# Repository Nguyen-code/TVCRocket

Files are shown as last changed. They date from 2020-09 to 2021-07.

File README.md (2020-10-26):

# About TVCRocket

This project was simultaneously one of the most challenging and most fun projects I've done in a while. I put myself on an extremely strict deadline, only 6 weeks for everything from planning launch sites to putting together 3 rockets (because I wanted to submit some of the work to colleges for applications) and I'm pleased with the progress I was able to make in that time. Going forward, I'm excited to continue development in future versions.

# Design Intent

The overarching goal of this project was to design and develop an active stability system for rockets on the model scale to learn more about robust hardware, software, and mechanical design. Although the first version didn't exactly work perfectly, I learned __SO MUCH__ and am excited to continue on version two, hopefully in the spring of 2021.

# Pictures!

### Zenith Boards (both controller and flight computer)
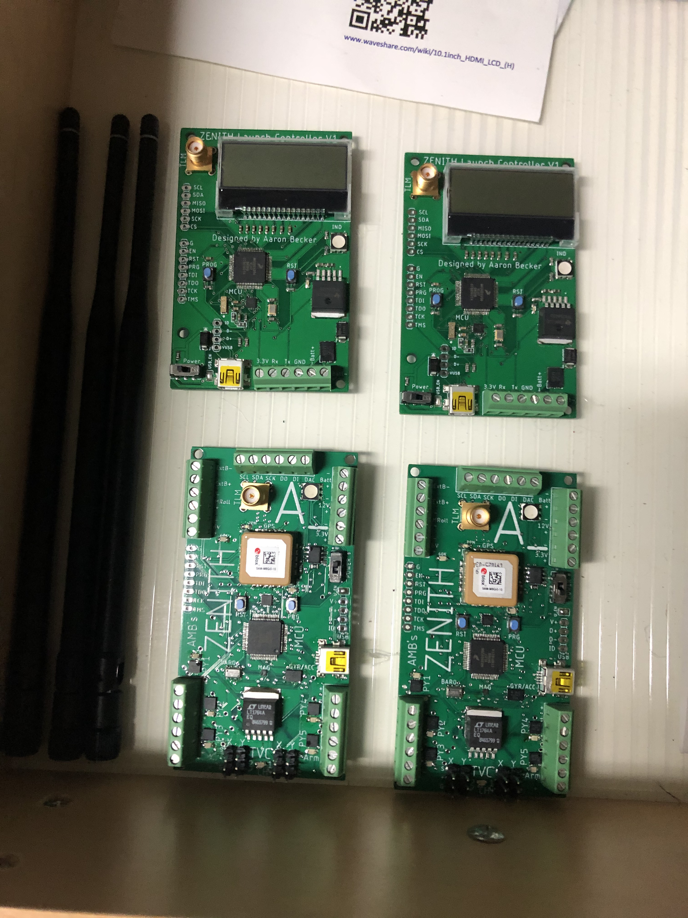
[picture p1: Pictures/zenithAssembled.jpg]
Zenith Boards Finalized


### Rockets before launch
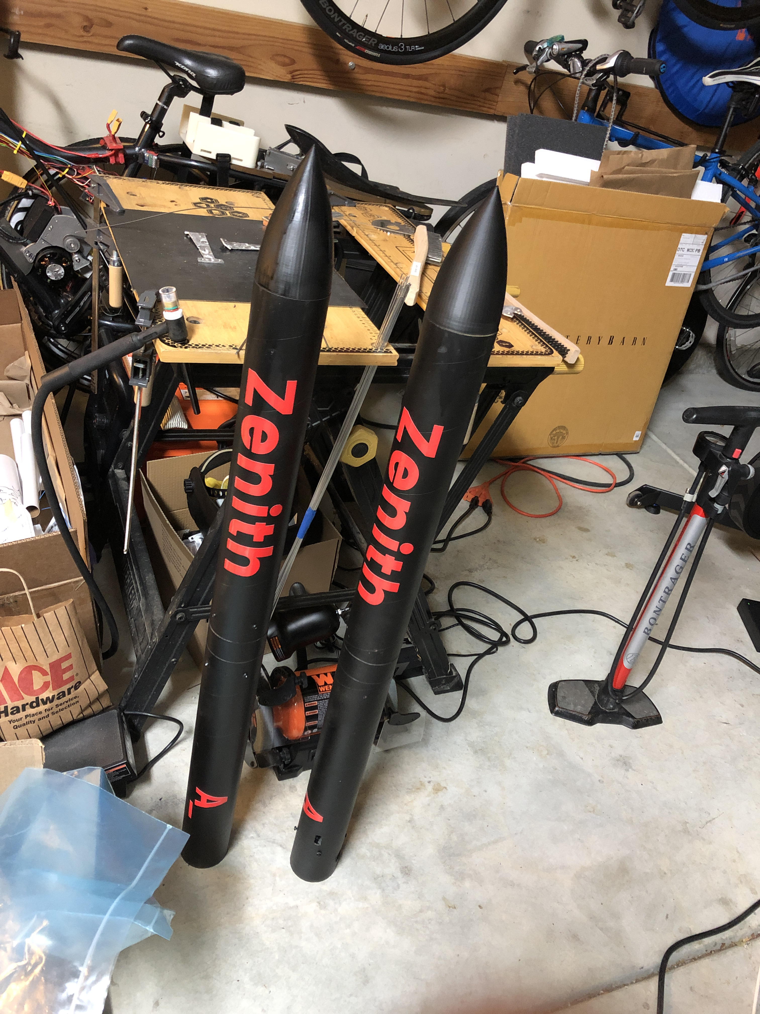
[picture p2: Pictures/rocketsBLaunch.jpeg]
Before Launch


### Rocket at launch site in tuning setup
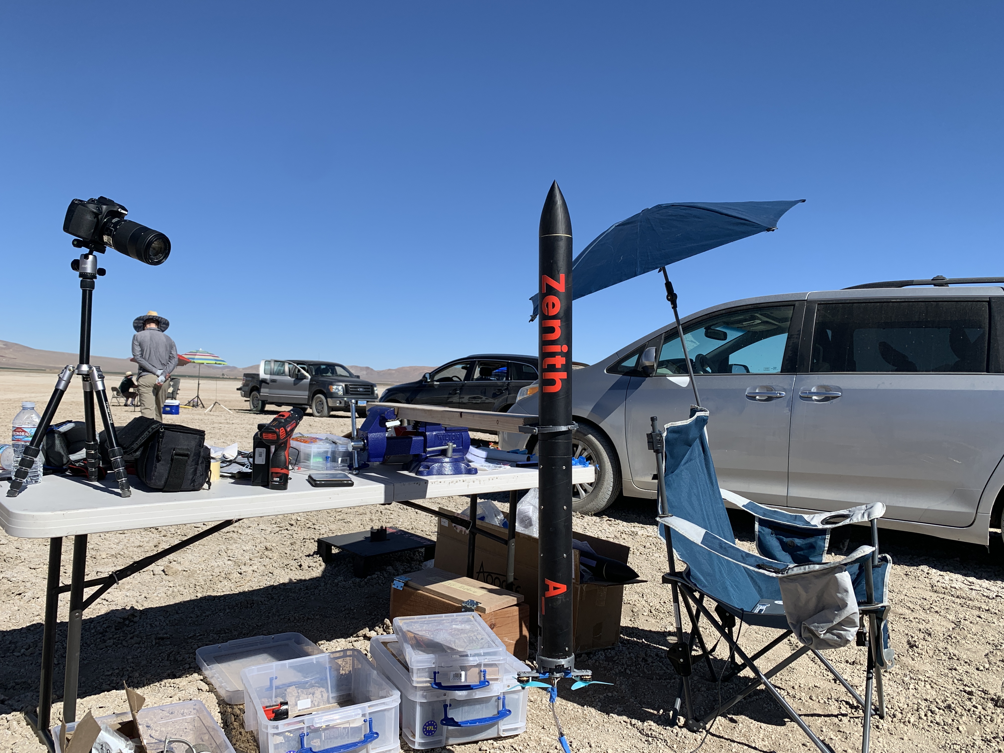
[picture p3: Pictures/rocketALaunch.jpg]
At Launch


# Renderings

## Zenith

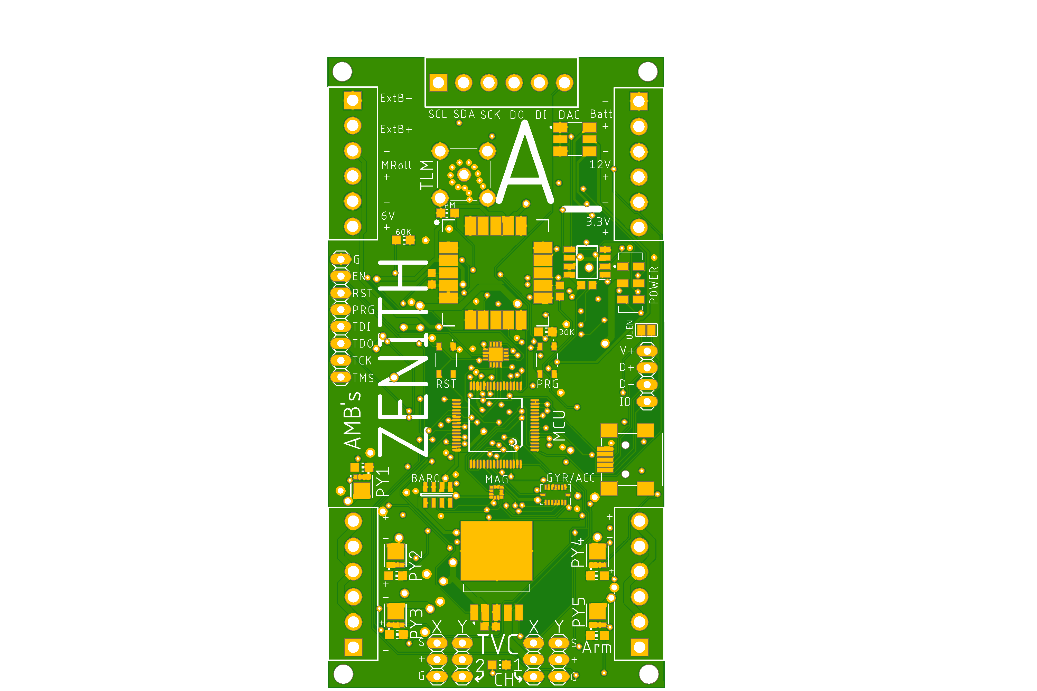
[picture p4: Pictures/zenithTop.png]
Zenith Top

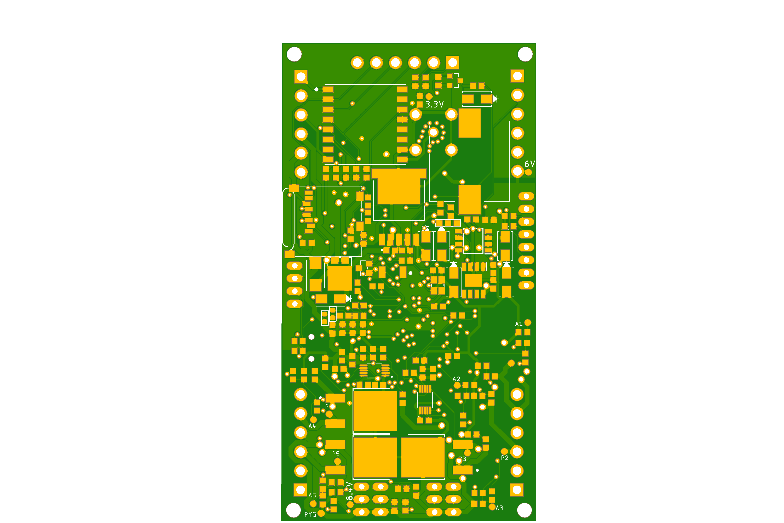
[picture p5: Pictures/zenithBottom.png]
Zenith Bottom


## Controller

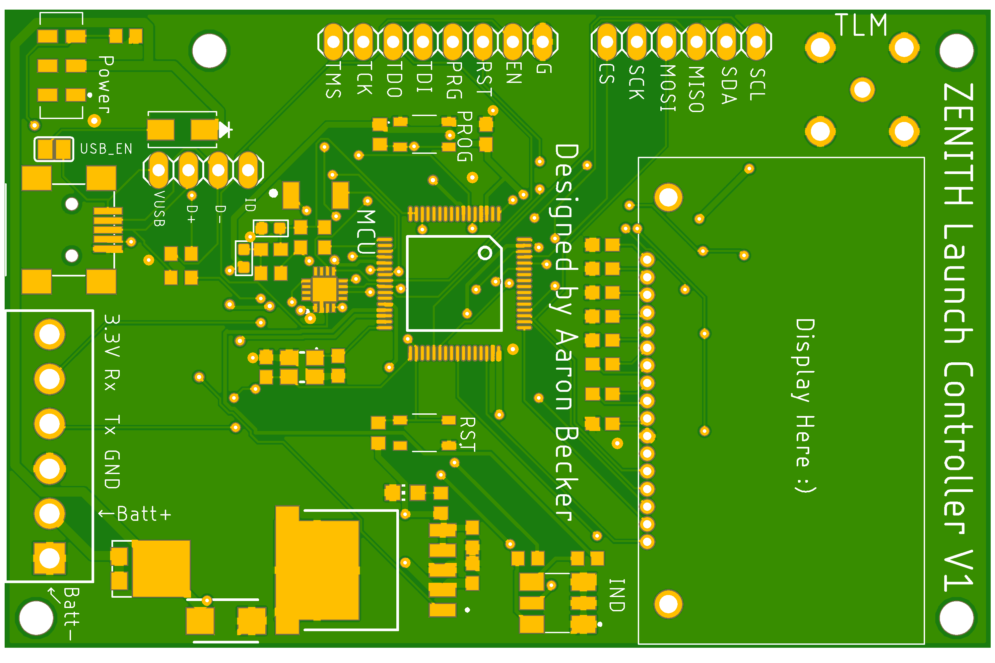
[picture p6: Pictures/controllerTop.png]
Zenith Controller Top

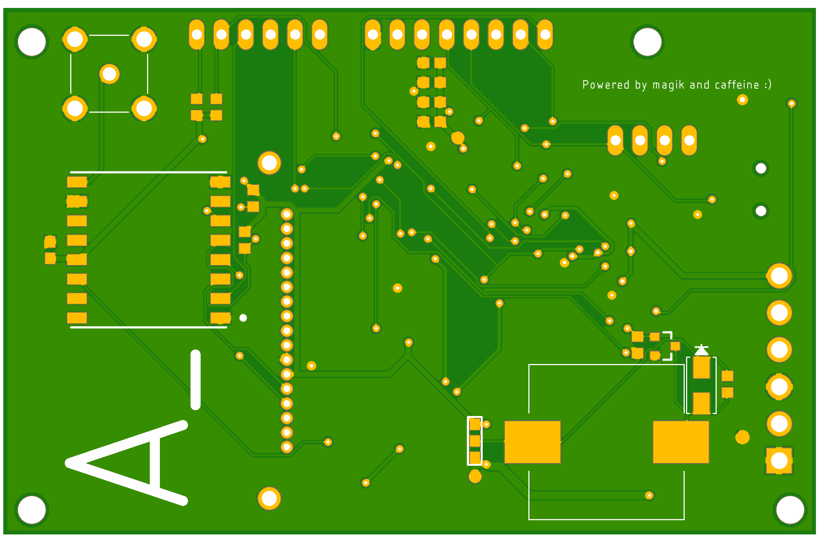
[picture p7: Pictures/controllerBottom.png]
Zenith Conrtoller Bottom


# Disclaimer

This repository contains Technical Data whose export is restricted by the Arms Export Control Act (Title 22, U.S.C., Sec 2751, et seq.). It is for educational purposes only and is not meant to be used in any scenarios which would put individuals in danger. When I launched my rocket, I strictly adhered with NAR/Tripoli safety codes. If you use anything from this repository for any means, you release me (Aaron Becker) from all liability and claims.

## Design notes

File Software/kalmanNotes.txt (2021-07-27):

kalman filter notes:

Reference code:
https://github.com/adafruit/Adafruit_AHRS/blob/master/src/Adafruit_AHRS_NXPFusion.cpp

EKF but python:
https://github.com/diegoavillegasg/IMU-GNSS-Lidar-sensor-fusion-using-Extended-Kalman-Filter-for-State-Estimation/blob/master/es_ekf.py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
https://github.com/diegoavillegasg/IMU-GNSS-Lidar-sensor-fusion-using-Extended-Kalman-Filter-for-State-Estimation/blob/master/es_ekf.py
https://github.com/cyscgzx33/Self_Driving_Car_State_Estimation/blob/master/state_estimate_final_proj/es_ekf.py

Kalman python but sim only:
https://github.com/tottaway/kalman-filters/blob/master/kalman.py

C++ EKF
https://github.com/rsasaki0109/kalman_filter_localization/blob/master/include/kalman_filter_localization/ekf.hpp

EKF but for drones
https://github.com/PX4/ecl

Apparently good theory
https://www.kalmanfilter.net/kalman1d.html

More notes and papers
https://www.researchgate.net/publication/260725857_Vehicle_speed_estimation_using_GPSRISS_Reduced_Inertial_Sensor_System
https://www.bzarg.com/p/how-a-kalman-filter-works-in-pictures/
https://www.mathworks.com/matlabcentral/fileexchange/56652-particle-sigma-point-and-kalman-filters
http://www.anuncommonlab.com/articles/how-kalman-filters-work/

Embedded lib w some great info at the top
https://github.com/pronenewbits/Embedded_EKF_Library/blob/master/ekf_engl/ekf.cpp
https://github.com/pronenewbits/Arduino_AHRS_System/blob/master/ahrs_ekf/ahrs_ekf.ino
https://github.com/pronenewbits/Arduino_AHRS_System/blob/master/ahrs_ekf/ekf.cpp

ACTUAL KALMAN FILTER IMPLEMENTATION FOR ARDUINO (USE THIS)
https://github.com/DanInvents/Flight-Controller
and
https://github.com/TKJElectronics/KalmanFilter/blob/master/examples/MPU6050/MPU6050.ino
https://github.com/FlyTheThings/uNavINS <---- THIS IS PERFECT FOR APPLICATION
https://github.com/ydsf16/imu_gps_localization/blob/master/imu_gps_localizer/src/imu_processor.cpp <---- ALSO THIS
ANOTHER ONE THAT JOE USED https://github.com/simondlevy/TinyEKF

more general sim ref stuff
https://github.com/Zentrik/TVC

BEST RESOURCE
https://github.com/rlabbe/Kalman-and-Bayesian-Filters-in-Python

Notes on Torque based controllers
https://youtu.be/J2ACQsmkPJs?t=411

Quaternion stuff
https://github.com/alexdada555/Rocket-Landing-Control/blob/master/ACS6116%20Assignment%20-%20Rocket%20Landing%20Control%20With%20MPC.pdf

State is represented by a matrix x
Each variable has a mean of mu and a variance of SD^2 - variance=uncertainty

Best estimate is x hat sub k - aka mean of readings
Covariance matrix is P sub k - represents the degree of correlation between the ith and jth state variable

Looking at current state at t=k-1, next state at time K can be mapped by a matrix F sub k, which moves every point to a new estimate

Update covariance matrix by using identity cov(Ax) = AcovAt

U sub k is the control vector - represents what the guidance system is doing to the system
B sub k is the control matrix - represents mapping of the control vector to the system

Add expanded covariance of Q sub k to the covariance matrix

"the new best estimate is a prediction made from previous best estimate, plus a correction for known external influences.

And the new uncertainty is predicted from the old uncertainty, with some additional uncertainty from the environment."

Sensors tell us something indirect about the state - they produce a set of readings
Sensors are modelled by a matrix, H sub k, which is used to map the readings to the state or covariance matrix

Covariance of the sensor uncertainty (i.e. noise) is the matrix R sub k, mean equal to the reading we observed which is a vector, z sub k

If we multiply H sub k and Z sub k, we get the intersection between uncertainty and the sensor reading, which gives us a nice best guess

K is kalman gain matrix that

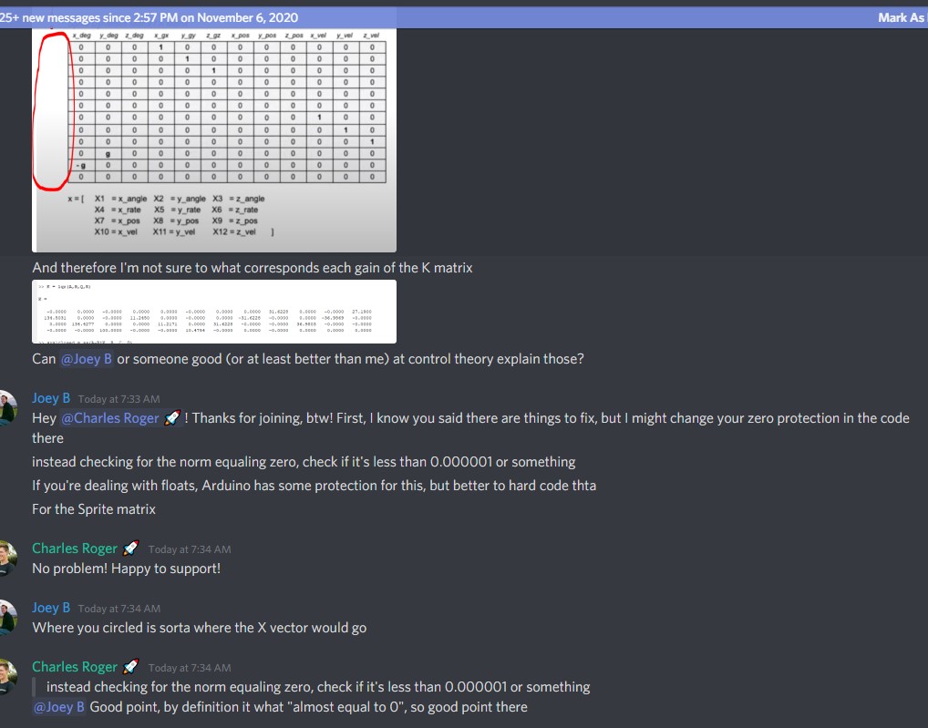
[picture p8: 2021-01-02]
Software/Reference/control theory matrices.jpg

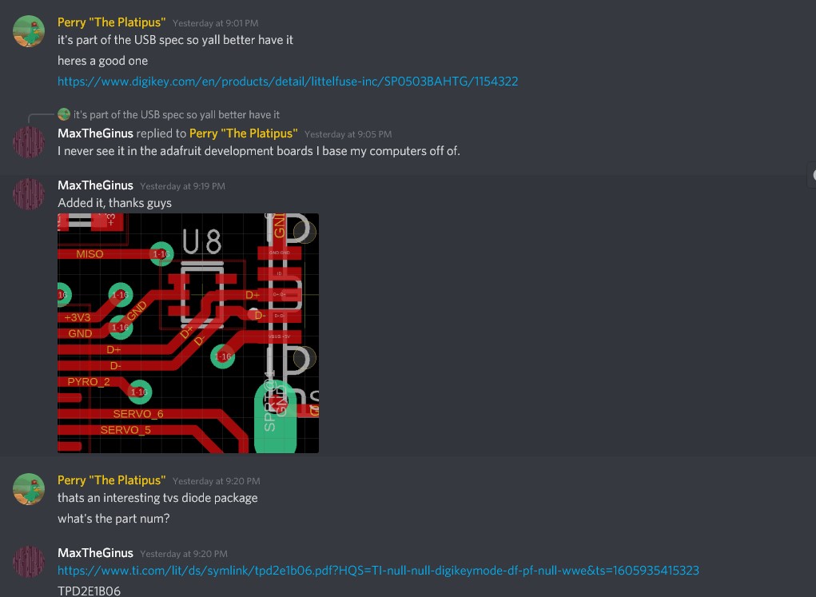
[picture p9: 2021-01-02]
Software/Reference/tvs diode usb spec.jpg

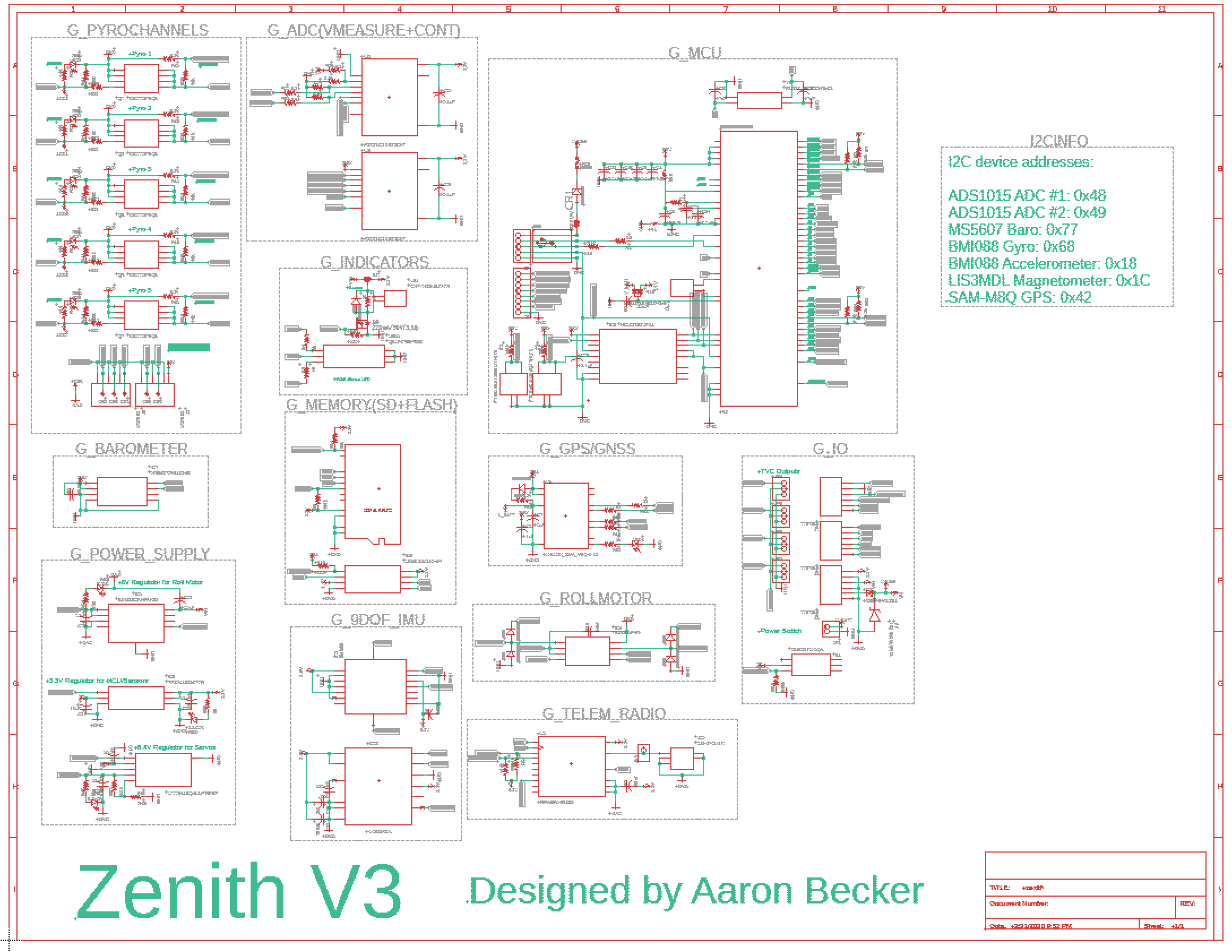
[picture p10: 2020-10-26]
Hardware/Rocket/zenithlowres.png

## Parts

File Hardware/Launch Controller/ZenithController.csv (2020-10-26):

Qty | Value | Device | Package | Parts | Description | ARROW_ELECTRONICS-PURCHASE-URL | ARROW_PART_NUMBER | ARROW_PRICE-STOCK | AVAILABILITY | BUILT_BY | DESC | DESCRIPTION | DIGIKEY-PURCHASE-URL | HEIGHT | MANUFACTURER_NAME | MANUFACTURER_PART_NUMBER | MF | MOUSER-PURCHASE-URL | MOUSER_PART_NUMBER | MOUSER_PRICE-STOCK | MP | MPN | OC_MOUSER | PACKAGE | POPULARITY | PRICE | PROD_ID | SOURCELIBRARY | SPICEPREFIX | TP_SIGNAL_NAME | TYPE | VALUE | VENDOR
2 |  | FERRITE | L0603 | BLM18AG601SN1D, R4 |  |  |  |  |  |  | 600R / 100MHz |  |  |  |  |  | Murata Electronics |  |  |  |  | BLM18AG601SN1D | 81-BLM11A601S | 0603 |  |  |  |  |  |  | Ferrite
1 |  | PINHD-1X4 | 1X04 | JP3 | PIN HEADER |  |  |  |  |  |  |  |  |  |  |  |  |  |  |  |  |  |  |  | 91
1 |  | PINHD-1X6 | 1X06 | JP1 | PIN HEADER |  |  |  |  |  |  |  |  |  |  |  |  |  |  |  |  |  |  |  | 79
1 |  | PINHD-1X8 | 1X08 | JP2 | PIN HEADER |  |  |  |  |  |  |  |  |  |  |  |  |  |  |  |  |  |  |  | 67
1 |  | SJ | SJ | USBPOW | SMD solder JUMPER |  |  |  |  |  |  |  |  |  |  |  |  |  |  |  |  |  |  |  | 33
1 |  | SOLDERJUMPER_2WAY0603 | SOLDERJUMPER_2WAY_OPEN_0603 | SJ1 | 2-Way Solder Jumper
1 |  | USBMINIB | USB-MINIB | CN1 | USB Connectors
6 | 0.1uF | C-USC0603 | C0603 | C3, C5, C18, C20, C23, C24 | CAPACITOR, American symbol |  |  |  |  |  |  |  |  |  |  |  |  |  |  |  |  |  |  |  | 37 |  |  |  | C
6 | 100k | R-US_R0603 | R0603 | R5, R14, R22, R57, R58, R66 | RESISTOR, American symbol |  |  |  |  |  |  |  |  |  |  |  |  |  |  |  |  |  |  |  | 77 |  |  |  | R
3 | 10uF | C-USC0603 | C0603 | C2, C21, C22 | CAPACITOR, American symbol |  |  |  |  |  |  |  |  |  |  |  |  |  |  |  |  |  |  |  | 37 |  |  |  | C
1 | 142-0701-211 | 142-0701-211 | 1420701211 | J10 | Cinch Connectors Straight 50 PCB Mount SMA Connector, jack, Solder Termination |  | 142-0701-211 | https://www.arrow.com/en/products/142-0701-211/cinch-connectivity-solutions |  |  |  | Cinch Connectors Straight 50 PCB Mount SMA Connector, jack, Solder Termination |  | 9.652mm | Cinch Connectivity Solutions | 142-0701-211 |  |  | 530-1420701211 | https://www.mouser.co.uk/ProductDetail/Johnson-Cinch-Connectivity-Solutions/142-0701-211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
1 | 1727052 | 1727052 | SHDR6W105P0X381_1X6_2285X730X8 | J3 | PHOENIX CONTACT - 1727052 - TERMINAL BLOCK, WIRE TO BRD, 6POS, 16AWG |  | 1727052 | https://www.arrow.com/en/products/1727052/phoenix-contact |  |  |  | PHOENIX CONTACT - 1727052 - TERMINAL BLOCK, WIRE TO BRD, 6POS, 16AWG |  | 8.65mm | Phoenix Contact | 1727052 |  |  | 651-1727052 | https://www.mouser.co.uk/ProductDetail/Phoenix-Contact/1727052?qs=WWq3Ki8dym7VpMyTMk0i8A%3D%3D
1 | 1SMB5929BT3G | 1SMB5929BT3G | DIOM5436X247N | Z2 | ON Semiconductor, 15V Zener Diode 5% 550 mW SMT 2-Pin SMB |  | 1SMB5929BT3G | https://www.arrow.com/en/products/1smb5929bt3g/on-semiconductor |  |  |  | ON Semiconductor, 15V Zener Diode 5% 550 mW SMT 2-Pin SMB |  | 2.47mm | ON Semiconductor | 1SMB5929BT3G |  |  | 863-1SMB5929BT3G | https://www.mouser.co.uk/ProductDetail/ON-Semiconductor/1SMB5929BT3G?qs=vLkC5FC1VN%2FFUr7OS2Q1Aw%3D%3D
1 | 1k | R-US_R0603 | R0603 | R7 | RESISTOR, American symbol |  |  |  |  |  |  |  |  |  |  |  |  |  |  |  |  |  |  |  | 77 |  |  |  | R
5 | 1uF | C-USC0603 | C0603 | C1, C7, C8, C9, C10 | CAPACITOR, American symbol |  |  |  |  |  |  |  |  |  |  |  |  |  |  |  |  |  |  |  | 37 |  |  |  | C
2 | 2.2k | R-US_R0603 | R0603 | R1, R2 | RESISTOR, American symbol |  |  |  |  |  |  |  |  |  |  |  |  |  |  |  |  |  |  |  | 77 |  |  |  | R
5 | 2.2uF | C-USC0603 | C0603 | C4, C6, C11, C12, C13 | CAPACITOR, American symbol |  |  |  |  |  |  |  |  |  |  |  |  |  |  |  |  |  |  |  | 37 |  |  |  | C
1 | 220mA/50V/3.5Ω | MOSFET-NCH-BSS138 | SOT23-3 | Q8 | N-channel MOSFETs |  |  |  |  |  |  |  |  |  |  |  |  |  |  |  |  |  |  |  |  |  | TRANS-00830 |  |  |  |  | 220mA/50V/3.5Ω
2 | 33 | R-US_R0603 | R0603 | R8, R16 | RESISTOR, American symbol |  |  |  |  |  |  |  |  |  |  |  |  |  |  |  |  |  |  |  | 77 |  |  |  | R
1 | 470 | R-US_R0603 | R0603 | R21 | RESISTOR, American symbol |  |  |  |  |  |  |  |  |  |  |  |  |  |  |  |  |  |  |  | 77 |  |  |  | R
1 | 5.6 | R-US_R0603 | R0603 | R6 | RESISTOR, American symbol |  |  |  |  |  |  |  |  |  |  |  |  |  |  |  |  |  |  |  | 77 |  |  |  | R
2 | 68 | R-US_R0603 | R0603 | R3, R60 | RESISTOR, American symbol |  |  |  |  |  |  |  |  |  |  |  |  |  |  |  |  |  |  |  | 77 |  |  |  | R
2 | 7pF | C-USC0603 | C0603 | C30, C31 | CAPACITOR, American symbol |  |  |  |  |  |  |  |  |  |  |  |  |  |  |  |  |  |  |  | 37 |  |  |  | C
1 | ABS10-32.768KHZ-9-T | ABS10-32.768KHZ-9-T | ABS-10 | Y2 | ABRACON - ABS10-32.768KHZ-9-T - Crystal, 32.768 kHz, SMD, 4.9mm x 1.8mm, 9 pF, 20 ppm, ABS10 Series |  | ABS10-32.768KHZ-9-T | https://www.arrow.com/en/products/abs10-32.768khz-9-t/abracon |  |  |  | ABRACON - ABS10-32.768KHZ-9-T - Crystal, 32.768 kHz, SMD, 4.9mm x 1.8mm, 9 pF, 20 ppm, ABS10 Series |  | mm | ABRACON | ABS10-32.768KHZ-9-T |  |  | 815-ABS10-32.768K9T | https://www.mouser.co.uk/ProductDetail/ABRACON/ABS10-32768KHZ-9-T?qs=76dmnhCH%2FMO8FcjiLkcQ2w%3D%3D
2 | B120-13-F | B120-13-F | SMA_DIO | CR1, CR2 |  |  |  |  |  | EMA_UL_Team |  |  |  |  |  | B120-13-F |  |  |  |  |  |  |  |  |  |  |  | DiodesInc_2015-05-08 |  |  |  |  | Diodes Inc
1 | CMT-1603-SMT-TR | CMT-1603-SMT-TR | CMT1603SMTTR | LS1 | AUDIO PIEZO TRANSDUCER 25V SMD |  | CMT-1603-SMT-TR | https://www.arrow.com/en/products/cmt-1603-smt-tr/cui-devices |  |  |  | AUDIO PIEZO TRANSDUCER 25V SMD |  | 2.8mm | CUI Devices | CMT-1603-SMT-TR |  |  | 490-CMT-1603-SMT-TR | https://www.mouser.co.uk/ProductDetail/CUI-Devices/CMT-1603-SMT-TR?qs=WyjlAZoYn50AZ4xT4ox6zw%3D%3D
1 | FA-238_16.0000MB-K3 | FA-238_16.0000MB-K3 | EPSON-FA-238 | FA-23816.0000MA30X-AG0 | Crystal 16MHz |  | FA-238 16.0000MB-K3 | https://www.arrow.com/en/products/fa-23816.0000mb-k3/epson-electronics-america |  |  |  | Crystal 16MHz |  | mm | Epson Timing | FA-238 16.0000MB-K3 |  |  | 732-FA238-16B-K3 | https://www.mouser.co.uk/ProductDetail/Epson-Timing/FA-238-160000MB-K3?qs=CANAagUtPAoF3w0fRAI0xg%3D%3D
1 | JS202011JCQN | JS202011JCQN | JS202011JCQN | S4 | Slide Switch DPDT Surface Mount |  | JS202011JCQN | https://www.arrow.com/en/products/js202011jcqn/ck |  |  |  | Slide Switch DPDT Surface Mount |  | 5mm | C & K COMPONENTS | JS202011JCQN |  |  | 611-JS202011JCQN | https://www.mouser.co.uk/ProductDetail/CK/JS202011JCQN?qs=74EMXstkWMXJzVJFnXPbEg%3D%3D
1 | MK20DX256VLH7 | MK20DX256VLH7 | LQFP64-05 | K3 |  |  |  |  |  |  | MK20DX256VLH7 |  |  |  |  |  | NXP |  |  |  |  | MK20DX256VLH7 | 841-MK20DX256VLH7 | LQFP-64 |  |  |  |  |  |  | Microcontroller
1 | MKL02Z32VFG4 | MKL02Z32VFG4 | QFN50P300X300X65-17N | IC5 | NXP MKL02Z32VFG4, 32bit ARM Cortex M0 Microcontroller, 48MHz, 32 kB Flash, 16-Pin QFN |  | MKL02Z32VFG4 | https://www.arrow.com/en/products/mkl02z32vfg4/nxp-semiconductors |  |  |  | NXP MKL02Z32VFG4, 32bit ARM Cortex M0 Microcontroller, 48MHz, 32 kB Flash, 16-Pin QFN |  | 0.65mm | NXP | MKL02Z32VFG4 |  |  | 841-MKL02Z32VFG4 | https://www.mouser.co.uk/ProductDetail/NXP-Semiconductors/MKL02Z32VFG4?qs=RECgZY%252BK1xLpPFD7GzHxWg%3D%3D
1 | NHD-C12832A1Z-FSW-FBW-3V3 | NHD-C12832A1Z-FSW-FBW-3V3 | NHDC12832A1ZFSWFBW3V3 | DS1 | LCD Graphic Display Modules & Accessories FSTN (+) 41.4 x 24.3 x 4.0 |  | NHD-C12832A1Z-FSW-FBW-3V3 |  |  |  |  | LCD Graphic Display Modules & Accessories FSTN (+) 41.4 x 24.3 x 4.0 |  | 4.3mm | Newhaven Display | NHD-C12832A1Z-FSW-FBW-3V3 |  |  | 763-C12832A1ZFSWFBW3 | https://www.mouser.co.uk/ProductDetail/Newhaven-Display/NHD-C12832A1Z-FSW-FBW-3V3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
2 | PTS810SJG250SMTRLFS | PTS810SJG250SMTRLFS | PTS810SJG250SMTRLFS | S2, S3 | PTS810SJG250SMTRLFS (Tactile Switches) Switch Tactile N.O. SPST Button J-Bend 0.05A 16VDC 100000Cycles 3.92N SMD T/R |  | PTS810SJG250SMTRLFS |  |  |  |  | PTS810SJG250SMTRLFS (Tactile Switches) Switch Tactile N.O. SPST Button J-Bend 0.05A 16VDC 100000Cycles 3.92N SMD T/R |  | 2.7mm | C & K COMPONENTS | PTS810SJG250SMTRLFS |  |  | 611-PTS810SJG250SMTR | https://www.mouser.co.uk/ProductDetail/CK/PTS810SJG250SMTRLFS?qs=UxeAxwACbqndUPIQjZosiw%3D%3D
1 | QBLP679E-RGB | QBLP679E-RGB | QBLP679ERGB | LED1 | LED RGB DIFFUSED 6PLCC SMD |  | QBLP679E-RGB |  |  |  |  | LED RGB DIFFUSED 6PLCC SMD |  | 1.8mm | QT Brightek (QTB) | QBLP679E-RGB
1 | RED | LEDCHIP-LED0805 | CHIP-LED0805 | 3.3VOK | LED |  |  |  |  |  |  |  |  |  |  |  |  |  |  |  |  |  |  |  | 68
1 | RFM95W-868S2 | RFM95W-868S2 | XCVR_RFM95W-868S2 | U1 | Mod Txrx Lora +20dbm 868mhz Smd |  |  |  | Unavailable |  |  | General ISM < 1GHz LoRa™ Transceiver Module 868MHz Antenna Not Included Surface Mount |  |  |  |  | RF |  |  |  | RFM95W-868S2 |  |  | SMD-16 Hope Microelectronics |  | None
1 | SS5P6-M3/86A | SS5P6-M3/86A | TO-277A(SMPC) | D2 | Vishay | https://snapeda.com/shop?store=Arrow+Electronics&id=580592 |  |  | Unavailable |  |  | Diode Schottky 60V 5A Surface Mount TO-277A (SMPC) | https://snapeda.com/shop?store=DigiKey&id=580592 |  |  |  | Vishay Semiconductor | https://snapeda.com/shop?store=Mouser&id=580592 |  |  | SS5P6-M3/86A |  |  | TO-277 Vishay Semiconductor |  | None
3 | TPB1,27 | TPB1,27 | B1,27 | 3.3V, GND, VIN | Test pad |  |  |  |  |  |  |  |  |  |  |  |  |  |  |  |  |  |  |  | 19
1 | TPS7A4533KTTR | TPS7A4533KTTR | KTT0005B | IC6 | Low-Noise Fast-Transient-Response 1.5-A Low-Dropout Voltage Regulators |  | TPS7A4533KTTR | https://www.arrow.com/en/products/tps7a4533kttr/texas-instruments |  |  |  | Low-Noise Fast-Transient-Response 1.5-A Low-Dropout Voltage Regulators |  | mm | Texas Instruments | TPS7A4533KTTR |  |  | 595-TPS7A4533KTTR | https://www.mouser.co.uk/ProductDetail/Texas-Instruments/TPS7A4533KTTR?qs=VdEABdpqjWy1AK9ieQmsYg%3D%3D

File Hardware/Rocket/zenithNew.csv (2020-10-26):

Qty | Value | Device | Package | Parts | Description | ARROW_ELECTRONICS-PURCHASE-URL | ARROW_PART_NUMBER | ARROW_PRICE-STOCK | AVAILABILITY | BUILT_BY | DESC | DESCRIPTION | DIGI-KEY_PART_NUMBER | DIGIKEY-PURCHASE-URL | HEIGHT | MANUFACTURER_NAME | MANUFACTURER_PART_NUMBER | MF | MOUSER-PURCHASE-URL | MOUSER_PART_NUMBER | MOUSER_PRICE-STOCK | MP | MPN | OC_MOUSER | PACKAGE | POPULARITY | PRICE | PROD_ID | SOURCELIBRARY | SPICEPREFIX | TEXAS_INSTRUMENTS-PURCHASE-URL | TP_SIGNAL_NAME | TYPE | VALUE | VENDOR
1 |  | DIODE_DUAL | SOT-23 | BAT54C,215 |  |  |  |  |  |  | Dual Schottky, common cat |  |  |  |  |  |  | NXP Semiconductors |  |  |  |  | BAT54C,215 | 771-BAT54C-T/R | SOT-23 |  |  |  |  |  |  |  | Diode
2 |  | FERRITE | L0603 | BLM18AG601SN1D, R4 |  |  |  |  |  |  | 600R / 100MHz |  |  |  |  |  |  | Murata Electronics |  |  |  |  | BLM18AG601SN1D | 81-BLM11A601S | 0603 |  |  |  |  |  |  |  | Ferrite
1 |  | LEDCHIP-LED0805 | CHIP-LED0805 | LED6 | LED |  |  |  |  |  |  |  |  |  |  |  |  |  |  |  |  |  |  |  |  | 68
4 |  | PINHD-1X3 | 1X03 | JP4, JP5, JP6, JP7 | PIN HEADER |  |  |  |  |  |  |  |  |  |  |  |  |  |  |  |  |  |  |  |  | 92
1 |  | PINHD-1X4 | 1X04 | JP3 | PIN HEADER |  |  |  |  |  |  |  |  |  |  |  |  |  |  |  |  |  |  |  |  | 91
1 |  | PINHD-1X8 | 1X08 | JP2 | PIN HEADER |  |  |  |  |  |  |  |  |  |  |  |  |  |  |  |  |  |  |  |  | 67
1 |  | SJ | SJ | USBPOW | SMD solder JUMPER |  |  |  |  |  |  |  |  |  |  |  |  |  |  |  |  |  |  |  |  | 33
1 |  | SOLDERJUMPER_2WAY0603 | SOLDERJUMPER_2WAY_OPEN_0603 | SJ1 | 2-Way Solder Jumper
1 |  | USBMINIB | USB-MINIB | CN1 | USB Connectors
8 | 0.1uF | C-USC0603 | C0603 | C3, C5, C10, C18, C19, C20, C23, C24 | CAPACITOR, American symbol |  |  |  |  |  |  |  |  |  |  |  |  |  |  |  |  |  |  |  |  | 37 |  |  |  | C
5 | 100 | R-US_R0603 | R0603 | R29, R33, R38, R43, R48 | RESISTOR, American symbol |  |  |  |  |  |  |  |  |  |  |  |  |  |  |  |  |  |  |  |  | 77 |  |  |  | R
1 | 1000 | R-US_R0603 | R0603 | R11 | RESISTOR, American symbol |  |  |  |  |  |  |  |  |  |  |  |  |  |  |  |  |  |  |  |  | 77 |  |  |  | R
13 | 100k | R-US_R0603 | R0603 | R5, R9, R12, R14, R22, R27, R34, R39, R44, R49, R57, R58, R66 | RESISTOR, American symbol |  |  |  |  |  |  |  |  |  |  |  |  |  |  |  |  |  |  |  |  | 77 |  |  |  | R
3 | 100nF | C-USC0603 | C0603 | C1, C9, C11 | CAPACITOR, American symbol |  |  |  |  |  |  |  |  |  |  |  |  |  |  |  |  |  |  |  |  | 37 |  |  |  | C
1 | 10k | R-US_R0603 | R0603 | R24 | RESISTOR, American symbol |  |  |  |  |  |  |  |  |  |  |  |  |  |  |  |  |  |  |  |  | 77 |  |  |  | R
8 | 10uF | C-USC0603 | C0603 | C2, C12, C15, C21, C22, C25, C26, C29 | CAPACITOR, American symbol |  |  |  |  |  |  |  |  |  |  |  |  |  |  |  |  |  |  |  |  | 37 |  |  |  | C
1 | 142-0701-211 | 142-0701-211 | 1420701211 | J10 | Cinch Connectors Straight 50 PCB Mount SMA Connector, jack, Solder Termination |  | 142-0701-211 | https://www.arrow.com/en/products/142-0701-211/cinch-connectivity-solutions |  |  |  | Cinch Connectors Straight 50 PCB Mount SMA Connector, jack, Solder Termination |  |  | 9.652mm | Cinch Connectivity Solutions | 142-0701-211 |  |  | 530-1420701211 | https://www.mouser.co.uk/ProductDetail/Johnson-Cinch-Connectivity-Solutions/142-0701-211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
5 | 1727052 | 1727052 | SHDR6W105P0X381_1X6_2285X730X8 | J1, J2, J3, J4, J9 | PHOENIX CONTACT - 1727052 - TERMINAL BLOCK, WIRE TO BRD, 6POS, 16AWG |  | 1727052 | https://www.arrow.com/en/products/1727052/phoenix-contact |  |  |  | PHOENIX CONTACT - 1727052 - TERMINAL BLOCK, WIRE TO BRD, 6POS, 16AWG |  |  | 8.65mm | Phoenix Contact | 1727052 |  |  | 651-1727052 | https://www.mouser.co.uk/ProductDetail/Phoenix-Contact/1727052?qs=WWq3Ki8dym7VpMyTMk0i8A%3D%3D
1 | 1SMB5929BT3G | 1SMB5929BT3G | DIOM5436X247N | Z2 | ON Semiconductor, 15V Zener Diode 5% 550 mW SMT 2-Pin SMB |  | 1SMB5929BT3G | https://www.arrow.com/en/products/1smb5929bt3g/on-semiconductor |  |  |  | ON Semiconductor, 15V Zener Diode 5% 550 mW SMT 2-Pin SMB |  |  | 2.47mm | ON Semiconductor | 1SMB5929BT3G |  |  | 863-1SMB5929BT3G | https://www.mouser.co.uk/ProductDetail/ON-Semiconductor/1SMB5929BT3G?qs=vLkC5FC1VN%2FFUr7OS2Q1Aw%3D%3D
8 | 1k | R-US_R0603 | R0603 | R7, R25, R30, R35, R40, R45, R50, R52 | RESISTOR, American symbol |  |  |  |  |  |  |  |  |  |  |  |  |  |  |  |  |  |  |  |  | 77 |  |  |  | R
2 | 1uF | C-USC0603 | C0603 | C7, C8 | CAPACITOR, American symbol |  |  |  |  |  |  |  |  |  |  |  |  |  |  |  |  |  |  |  |  | 37 |  |  |  | C
4 | 2.2k | R-US_R0603 | R0603 | R1, R2, R63, R64 | RESISTOR, American symbol |  |  |  |  |  |  |  |  |  |  |  |  |  |  |  |  |  |  |  |  | 77 |  |  |  | R
2 | 2.2uF | C-USC0603 | C0603 | C4, C6 | CAPACITOR, American symbol |  |  |  |  |  |  |  |  |  |  |  |  |  |  |  |  |  |  |  |  | 37 |  |  |  | C
2 | 22 | R-US_R0603 | R0603 | R53, R54 | RESISTOR, American symbol |  |  |  |  |  |  |  |  |  |  |  |  |  |  |  |  |  |  |  |  | 77 |  |  |  | R
6 | 220 | R-US_R0603 | R0603 | R23, R32, R37, R42, R47, R59 | RESISTOR, American symbol |  |  |  |  |  |  |  |  |  |  |  |  |  |  |  |  |  |  |  |  | 77 |  |  |  | R
1 | 220mA/50V/3.5Ω | MOSFET-NCH-BSS138 | SOT23-3 | Q8 | N-channel MOSFETs |  |  |  |  |  |  |  |  |  |  |  |  |  |  |  |  |  |  |  |  |  |  | TRANS-00830 |  |  |  |  |  | 220mA/50V/3.5Ω
2 | 3.3k | R-US_R0603 | R0603 | R15, R61 | RESISTOR, American symbol |  |  |  |  |  |  |  |  |  |  |  |  |  |  |  |  |  |  |  |  | 77 |  |  |  | R
2 | 33 | R-US_R0603 | R0603 | R8, R16 | RESISTOR, American symbol |  |  |  |  |  |  |  |  |  |  |  |  |  |  |  |  |  |  |  |  | 77 |  |  |  | R
7 | 330 | R-US_R0603 | R0603 | R26, R31, R36, R41, R46, R51, R65 | RESISTOR, American symbol |  |  |  |  |  |  |  |  |  |  |  |  |  |  |  |  |  |  |  |  | 77 |  |  |  | R
3 | 470 | R-US_R0603 | R0603 | R17, R18, R21 | RESISTOR, American symbol |  |  |  |  |  |  |  |  |  |  |  |  |  |  |  |  |  |  |  |  | 77 |  |  |  | R
1 | 5.6 | R-US_R0603 | R0603 | R6 | RESISTOR, American symbol |  |  |  |  |  |  |  |  |  |  |  |  |  |  |  |  |  |  |  |  | 77 |  |  |  | R
2 | 560 | R-US_R0603 | R0603 | R62, R68 | RESISTOR, American symbol |  |  |  |  |  |  |  |  |  |  |  |  |  |  |  |  |  |  |  |  | 77 |  |  |  | R
1 | 620 | R-US_R0603 | R0603 | R10 | RESISTOR, American symbol |  |  |  |  |  |  |  |  |  |  |  |  |  |  |  |  |  |  |  |  | 77 |  |  |  | R
2 | 68 | R-US_R0603 | R0603 | R3, R60 | RESISTOR, American symbol |  |  |  |  |  |  |  |  |  |  |  |  |  |  |  |  |  |  |  |  | 77 |  |  |  | R
1 | 680 | R-US_R0603 | R0603 | R67 | RESISTOR, American symbol |  |  |  |  |  |  |  |  |  |  |  |  |  |  |  |  |  |  |  |  | 77 |  |  |  | R
2 | 7pF | C-USC0603 | C0603 | C30, C31 | CAPACITOR, American symbol |  |  |  |  |  |  |  |  |  |  |  |  |  |  |  |  |  |  |  |  | 37 |  |  |  | C
1 | ABS10-32.768KHZ-9-T | ABS10-32.768KHZ-9-T | ABS-10 | Y2 | ABRACON - ABS10-32.768KHZ-9-T - Crystal, 32.768 kHz, SMD, 4.9mm x 1.8mm, 9 pF, 20 ppm, ABS10 Series |  | ABS10-32.768KHZ-9-T | https://www.arrow.com/en/products/abs10-32.768khz-9-t/abracon |  |  |  | ABRACON - ABS10-32.768KHZ-9-T - Crystal, 32.768 kHz, SMD, 4.9mm x 1.8mm, 9 pF, 20 ppm, ABS10 Series |  |  | mm | ABRACON | ABS10-32.768KHZ-9-T |  |  | 815-ABS10-32.768K9T | https://www.mouser.co.uk/ProductDetail/ABRACON/ABS10-32768KHZ-9-T?qs=76dmnhCH%2FMO8FcjiLkcQ2w%3D%3D
2 | ADS1015IDGST | ADS1015IDGST | SOP50P490X110-10N | U2, U6 |  |  |  |  |  |  |  | 12-Bit, 3.3kSPS, 4-Ch Delta-Sigma ADC With PGA, Oscillator, VREF, Comparator and I2C Interface 10-VSSOP -40 to 125 | 296-25227-1-ND |  |  |  |  | Texas Instruments |  |  |  | ADS1015IDGST |  |  | VSSOP-10 Texas Instruments |  |  |  |  |  | https://snapeda.com/shop?store=Texas+Instruments&id=425936
4 | B120-13-F | B120-13-F | SMA_DIO | CR1, CR2, CR5, CR6 |  |  |  |  |  | EMA_UL_Team |  |  |  |  |  |  | B120-13-F |  |  |  |  |  |  |  |  |  |  |  | DiodesInc_2015-05-08 |  |  |  |  |  | Diodes Inc
3 | B120-13-FNO_LABELS | B120-13-FNO_LABELS | SMA_NO_LABELS | CR3, CR4, CR7
1 | BD60GC0WEFJ-E2 | BD60GC0WEFJ-E2 | SOIC127P600X100-9N | IC1 | LDO Regulator 6V 1% 1A 4.5-14V HTSOP8 |  | BD60GC0WEFJ-E2 |  |  |  |  | LDO Regulator 6V 1% 1A 4.5-14V HTSOP8 |  |  | 1mm | ROHM Semiconductor | BD60GC0WEFJ-E2 |  |  | 755-BD60GC0WEFJ-E2 | https://www.mouser.co.uk/ProductDetail/ROHM-Semiconductor/BD60GC0WEFJ-E2?qs=QbAZ1slfEbRabsfnpcxbEg%3D%3D
1 | BD6211F-E2 | BD6211F-E2 | SOIC127P620X171-8N | IC4 | ROHM BD6211F-E2, Full Bridge Motor Driver Half-Bridge,, 8-Pin SOP |  | BD6211F-E2 | https://www.arrow.com/en/products/bd6211f-e2/rohm-semiconductor |  |  |  | ROHM BD6211F-E2, Full Bridge Motor Driver Half-Bridge,, 8-Pin SOP |  |  | 1.71mm | ROHM Semiconductor | BD6211F-E2 |  |  | 755-BD6211F-E2 | https://www.mouser.co.uk/ProductDetail/ROHM-Semiconductor/BD6211F-E2?qs=WqWCsLCZBkoJxAu8uKdYEg%3D%3D
1 | BMI088 | BMI088 | BMI088 | IC2 | Inertial Measurement Unit Digital Output 2.5V/3.3V Automotive |  | BMI088 | https://www.arrow.com/en/products/bmi088/bosch |  |  |  | Inertial Measurement Unit Digital Output 2.5V/3.3V Automotive |  |  | 1.45mm | Bosch Sensortec | BMI088 |  |  | 262-BMI088 | https://www.mouser.co.uk/ProductDetail/Bosch-Sensortec/BMI088?qs=f9yNj16SXrIMFspTV6RB6Q%3D%3D
1 | BMM150 | BMM150 | BMM150 | IC3 | Board Mount Hall Effect / Magnetic Sensors 3-Axis 1.56x1.56mm WLCSP-12 Geomagnetic |  | BMM150 | https://www.arrow.com/en/products/bmm150/bosch |  |  |  | Board Mount Hall Effect / Magnetic Sensors 3-Axis 1.56x1.56mm WLCSP-12 Geomagnetic |  |  | 0.6mm | Bosch Sensortec | BMM150 |  |  | 262-BMM150 | https://www.mouser.co.uk/ProductDetail/Bosch-Sensortec/BMM150?qs=d72FGnIDsgTOmKpCEe6mYw%3D%3D
1 | CMT-1603-SMT-TR | CMT-1603-SMT-TR | CMT1603SMTTR | LS1 | AUDIO PIEZO TRANSDUCER 25V SMD |  | CMT-1603-SMT-TR | https://www.arrow.com/en/products/cmt-1603-smt-tr/cui-devices |  |  |  | AUDIO PIEZO TRANSDUCER 25V SMD |  |  | 2.8mm | CUI Devices | CMT-1603-SMT-TR |  |  | 490-CMT-1603-SMT-TR | https://www.mouser.co.uk/ProductDetail/CUI-Devices/CMT-1603-SMT-TR?qs=WyjlAZoYn50AZ4xT4ox6zw%3D%3D
5 | CSD17575Q3 | CSD17575Q3 | CSD16327 | Q1, Q2, Q5, Q6, Q7 | 30V, N ch NexFET MOSFET, single SON3x3, 3.2mOhm |  | CSD17575Q3 | https://www.arrow.com/en/products/csd17575q3/texas-instruments |  |  |  | 30V, N ch NexFET MOSFET, single SON3x3, 3.2mOhm |  |  | mm | Texas Instruments | CSD17575Q3 |  |  | 595-CSD17575Q3 | https://www.mouser.co.uk/ProductDetail/Texas-Instruments/CSD17575Q3?qs=1MXlzafEN3%2FTIl0%2FpyGUYQ%3D%3D
1 | FA-238_16.0000MB-K3 | FA-238_16.0000MB-K3 | EPSON-FA-238 | FA-23816.0000MA30X-AG0 | Crystal 16MHz |  | FA-238 16.0000MB-K3 | https://www.arrow.com/en/products/fa-23816.0000mb-k3/epson-electronics-america |  |  |  | Crystal 16MHz |  |  | mm | Epson Timing | FA-238 16.0000MB-K3 |  |  | 732-FA238-16B-K3 | https://www.mouser.co.uk/ProductDetail/Epson-Timing/FA-238-160000MB-K3?qs=CANAagUtPAoF3w0fRAI0xg%3D%3D
1 | JS202011JCQN | JS202011JCQN | JS202011JCQN | S4 | Slide Switch DPDT Surface Mount |  | JS202011JCQN | https://www.arrow.com/en/products/js202011jcqn/ck |  |  |  | Slide Switch DPDT Surface Mount |  |  | 5mm | C & K COMPONENTS | JS202011JCQN |  |  | 611-JS202011JCQN | https://www.mouser.co.uk/ProductDetail/CK/JS202011JCQN?qs=74EMXstkWMXJzVJFnXPbEg%3D%3D
1 | LE25U40CMC-AH | LE25U40CMC-AH | SOIC127P600X175-8N | IC9 | Source: Datasheet |  | LE25U40CMC-AH | https://www.arrow.com/en/products/le25u40cmc-ah/on-semiconductor |  |  |  |  |  |  | 1.75mm | ON Semiconductor | LE25U40CMC-AH |  |  | 863-LE25U40CMC-AH | https://www.mouser.co.uk/ProductDetail/ON-Semiconductor/LE25U40CMC-AH?qs=5C9Q4QJFsuOaZKXg58P8RA%3D%3D
1 | LT1764AEQ-3.3#TRPBF | LT1764AEQ-3.3#TRPBF | LT1764AEQ33TRPBF | LT1764#TRPBF | LDO Voltage Regulators 3A, Fast Tran Resp, L N, LDO Regs |  | LT1764AEQ-3.3#TRPBF |  |  |  |  | LDO Voltage Regulators 3A, Fast Tran Resp, L N, LDO Regs |  |  | 4.572mm | Linear Technology | LT1764AEQ-3.3#TRPBF |  |  | 584-1764AEQ-3.3TRPBF | https://www.mouser.co.uk/ProductDetail/Analog-Devices-Linear-Technology/LT1764AEQ-33TRPBF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
1 | MICROSD | MICROSD | MICROSD | 0473340001 | Micro-SD / Transflash card holder with SPI pinout
1 | MK20DX256VLH7 | MK20DX256VLH7 | LQFP64-05 | K3 |  |  |  |  |  |  | MK20DX256VLH7 |  |  |  |  |  |  | NXP |  |  |  |  | MK20DX256VLH7 | 841-MK20DX256VLH7 | LQFP-64 |  |  |  |  |  |  |  | Microcontroller
1 | MKL02Z32VFG4 | MKL02Z32VFG4 | QFN50P300X300X65-17N | IC5 | NXP MKL02Z32VFG4, 32bit ARM Cortex M0 Microcontroller, 48MHz, 32 kB Flash, 16-Pin QFN |  | MKL02Z32VFG4 | https://www.arrow.com/en/products/mkl02z32vfg4/nxp-semiconductors |  |  |  | NXP MKL02Z32VFG4, 32bit ARM Cortex M0 Microcontroller, 48MHz, 32 kB Flash, 16-Pin QFN |  |  | 0.65mm | NXP | MKL02Z32VFG4 |  |  | 841-MKL02Z32VFG4 | https://www.mouser.co.uk/ProductDetail/NXP-Semiconductors/MKL02Z32VFG4?qs=RECgZY%252BK1xLpPFD7GzHxWg%3D%3D
1 | MS561101BA03-00 | MS561101BA03-00 | SON125P300X500X100-8N | IC7 | MS561101BA03-50, Barometric Pressure Sensor, 1200mbar 0 3.6 V Output, 8-Pin QFN |  | MS561101BA03-00 | https://www.arrow.com/en/products/ms561101ba03-00/te-connectivity |  |  |  | MS561101BA03-50, Barometric Pressure Sensor, 1200mbar 0 3.6 V Output, 8-Pin QFN |  |  | 1mm | TE Connectivity | MS561101BA03-00 |  |  | 824-MS561101BA03-00 | https://www.mouser.com/Search/Refine.aspx?Keyword=824-MS561101BA03-00
2 | PTS810SJG250SMTRLFS | PTS810SJG250SMTRLFS | PTS810SJG250SMTRLFS | S2, S3 | PTS810SJG250SMTRLFS (Tactile Switches) Switch Tactile N.O. SPST Button J-Bend 0.05A 16VDC 100000Cycles 3.92N SMD T/R |  | PTS810SJG250SMTRLFS |  |  |  |  | PTS810SJG250SMTRLFS (Tactile Switches) Switch Tactile N.O. SPST Button J-Bend 0.05A 16VDC 100000Cycles 3.92N SMD T/R |  |  | 2.7mm | C & K COMPONENTS | PTS810SJG250SMTRLFS |  |  | 611-PTS810SJG250SMTR | https://www.mouser.co.uk/ProductDetail/CK/PTS810SJG250SMTRLFS?qs=UxeAxwACbqndUPIQjZosiw%3D%3D
3 | PWR163S-25-2R20J | PWR163S-25-2R20J | PWR163_DPAK | R28, R55, R69 | Thick Film Resistors - SMD 25watts 5% 2.2Ohm DPAK |  | PWR163S-25-2R20J |  |  |  |  | Thick Film Resistors - SMD 25watts 5% 2.2Ohm DPAK |  |  | mm | Bourns | PWR163S-25-2R20J |  |  | 652-PWR163S-25-2R20J | https://www.mouser.co.uk/ProductDetail/Bourns/PWR163S-25-2R20J?qs=Irp2sZejZDSl03BQqaIVVg%3D%3D
1 | QBLP679E-RGB | QBLP679E-RGB | QBLP679ERGB | LED1 | LED RGB DIFFUSED 6PLCC SMD |  | QBLP679E-RGB |  |  |  |  | LED RGB DIFFUSED 6PLCC SMD |  |  | 1.8mm | QT Brightek (QTB) | QBLP679E-RGB
8 | RED | LEDCHIP-LED0805 | CHIP-LED0805 | 3.3VOK, 6OK, 8.4VOK, LED2, LED3, LED4, LED7, LED8 | LED |  |  |  |  |  |  |  |  |  |  |  |  |  |  |  |  |  |  |  |  | 68
1 | RFM95W-868S2 | RFM95W-868S2 | XCVR_RFM95W-868S2 | U1 | Mod Txrx Lora +20dbm 868mhz Smd |  |  |  | Unavailable |  |  | General ISM < 1GHz LoRa™ Transceiver Module 868MHz Antenna Not Included Surface Mount |  |  |  |  |  | RF |  |  |  | RFM95W-868S2 |  |  | SMD-16 Hope Microelectronics |  | None
1 | SS5P6-M3/86A | SS5P6-M3/86A | TO-277A(SMPC) | D2 | Vishay | https://snapeda.com/shop?store=Arrow+Electronics&id=580592 |  |  | Unavailable |  |  | Diode Schottky 60V 5A Surface Mount TO-277A (SMPC) |  | https://snapeda.com/shop?store=DigiKey&id=580592 |  |  |  | Vishay Semiconductor | https://snapeda.com/shop?store=Mouser&id=580592 |  |  | SS5P6-M3/86A |  |  | TO-277 Vishay Semiconductor |  | None
14 | TPB1,27 | TPB1,27 | B1,27 | 3.3V, 6V, 8.4V, ACC3, ACC4, ACC5, ACC6, ACC7, CE1, CE2, CE3, CE4, CE5, CE6 | Test pad |  |  |  |  |  |  |  |  |  |  |  |  |  |  |  |  |  |  |  |  | 19
1 | TPS7A4533KTTR | TPS7A4533KTTR | KTT0005B | IC6 | Low-Noise Fast-Transient-Response 1.5-A Low-Dropout Voltage Regulators |  | TPS7A4533KTTR | https://www.arrow.com/en/products/tps7a4533kttr/texas-instruments |  |  |  | Low-Noise Fast-Transient-Response 1.5-A Low-Dropout Voltage Regulators |  |  | mm | Texas Instruments | TPS7A4533KTTR |  |  | 595-TPS7A4533KTTR | https://www.mouser.co.uk/ProductDetail/Texas-Instruments/TPS7A4533KTTR?qs=VdEABdpqjWy1AK9ieQmsYg%3D%3D
1 | U-BLOX_SAM_M8Q-0-10 | U-BLOX_SAM_M8Q-0-10 | SAM-M8Q | U4 | u-blox SAM-M8Q |  |  |  |  |  |  |  |  |  |  |  |  |  |  |  |  |  |  |  |  |  |  | IC-14070

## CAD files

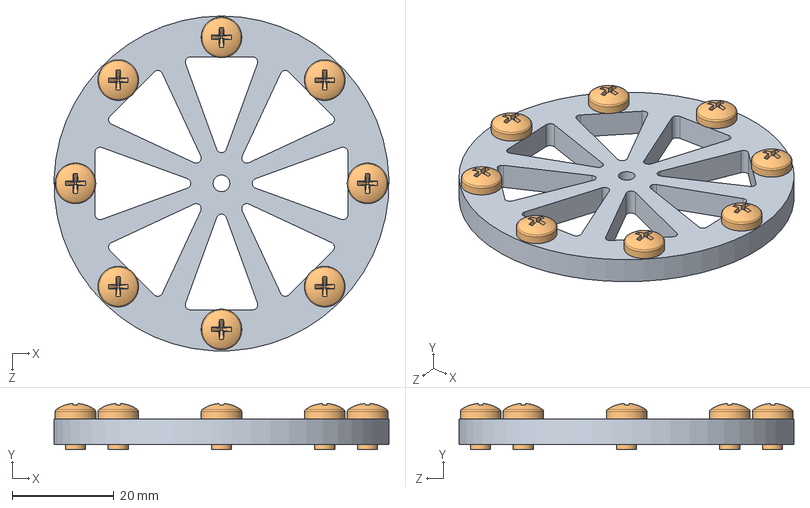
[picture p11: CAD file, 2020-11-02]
Mechanical Design/guidanceComputerMount/sim assem for rollwheel.SLDASM
66.0 x 9.07 x 66.0 mm
rollwheeeel
pan cross head_am x 8

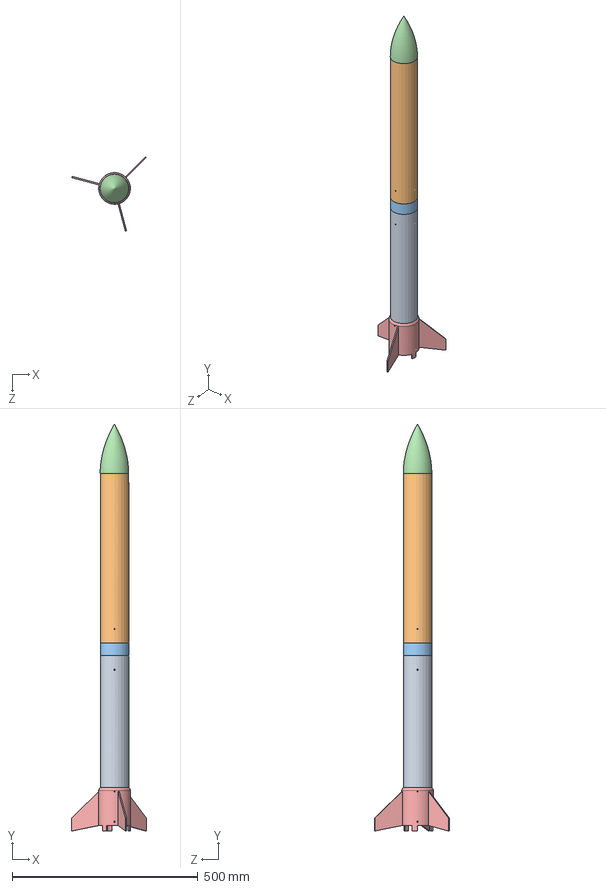
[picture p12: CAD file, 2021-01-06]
Mechanical Design/rocket v1 for stl display.SLDASM
200.7 x 1096.5 x 200.7 mm
body tube bottom
body tube top
coupler
nosecone
rocketPadConnectorTop

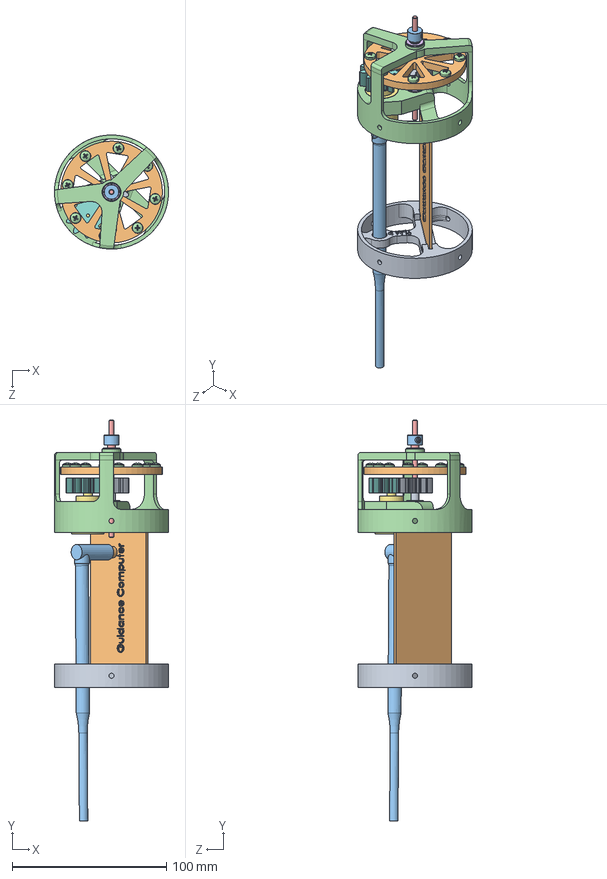
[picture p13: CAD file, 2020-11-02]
Mechanical Design/guidanceComputerMount/guidance computer assem.SLDASM
74.0 x 260.1 x 74.0 mm
guidance mount bottom
guidance computer
antenna
guidance mount top
1327K930_MINIATURE 12L14 DRIVE STEEL SHAFT
57155K207_STAINLESS STEEL BALL BEARING x 2
rollmotor
gear1
gear2
rollwheeeel
pan cross head_am x 8
clampingSpacer

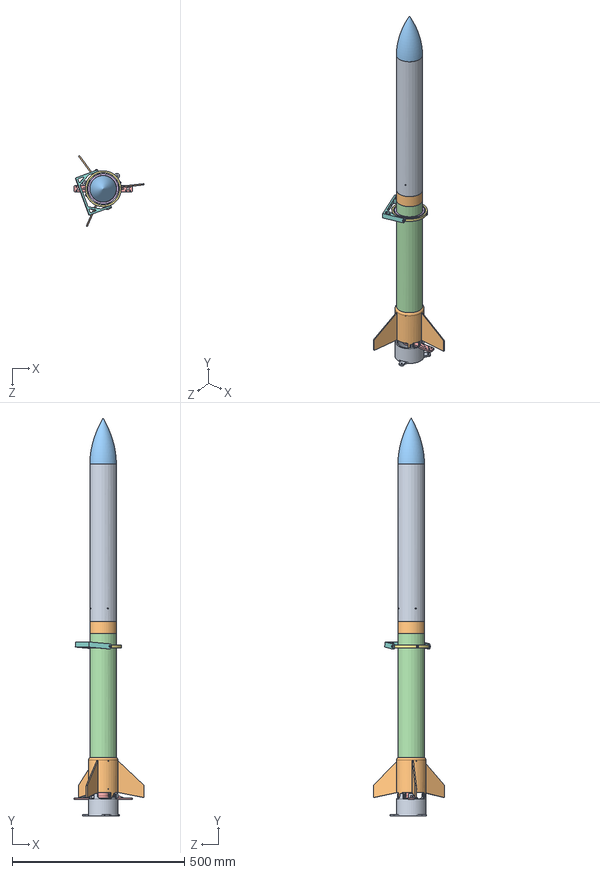
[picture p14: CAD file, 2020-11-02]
Mechanical Design/rocket v1.SLDASM
203.4 x 1153.8 x 206.6 mm
body tube top
coupler
nosecone
body tube bottom
BPS.space R2-74 Sleeve
BPS.space R2-74 Inner Gimbal
BPS.space R2-74 Outer Gimbal
guidance mount bottom
guidance computer
antenna
guidance mount top
1327K930_MINIATURE 12L14 DRIVE STEEL SHAFT
57155K207_STAINLESS STEEL BALL BEARING x 2
rollmotor
gear1
gear2
rollwheeeel
pan cross head_am x 14
clampingSpacer
testMount
gimbalInner
gimbalOuter
gimbalOutside
rocketPadConnectorBottom

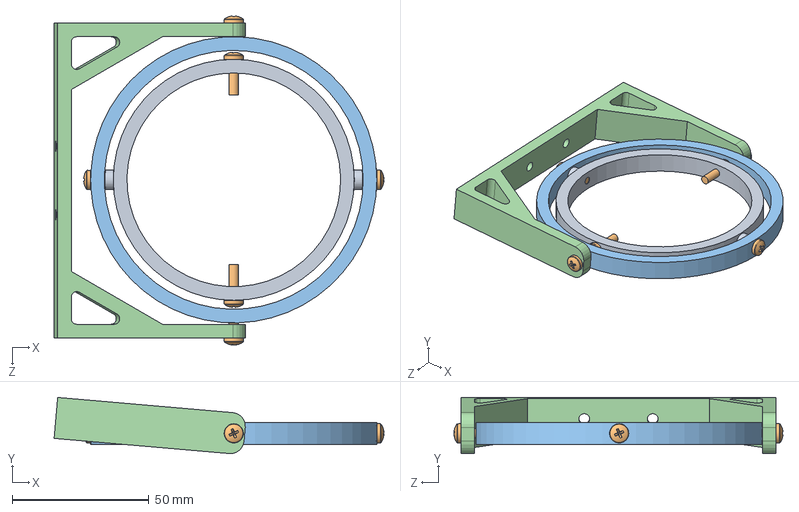
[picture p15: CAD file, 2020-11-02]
Mechanical Design/gimbalAssem.SLDASM
120.4 x 20.5 x 120.1 mm
gimbalInner
pan cross head_am x 6
gimbalOuter
gimbalOutside

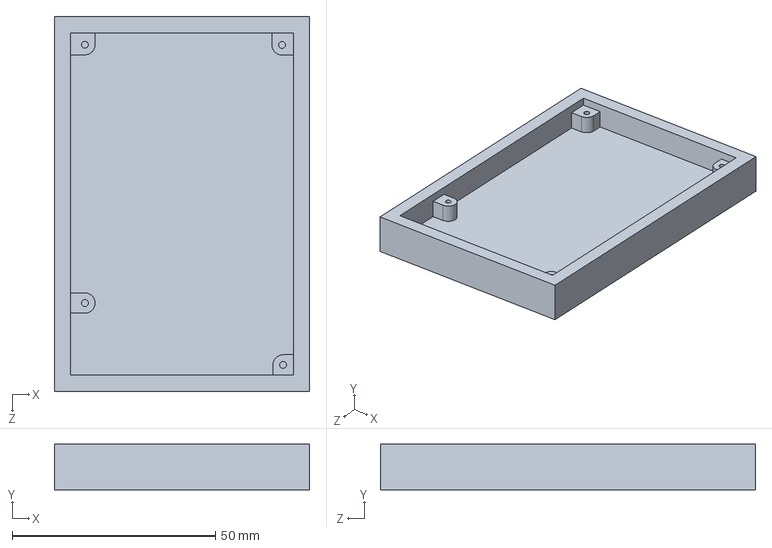
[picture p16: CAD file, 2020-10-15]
Mechanical Design/controllerBox/box.SLDPRT
62.7 x 11.2 x 92.2 mm

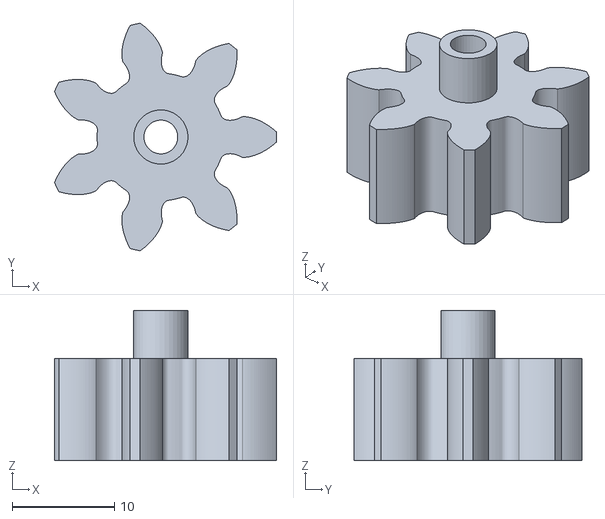
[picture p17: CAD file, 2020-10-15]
Mechanical Design/guidanceComputerMount/gear/gear2-95.STL
21.7 x 22.3 x 14.7

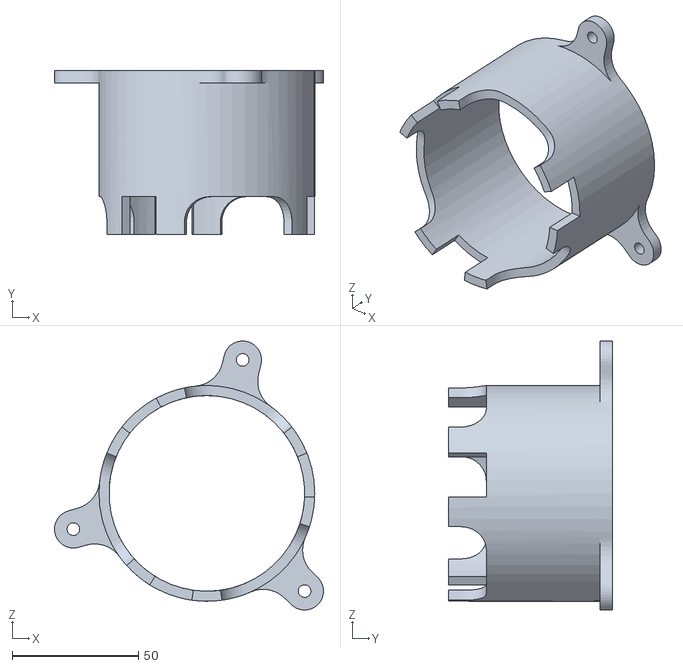
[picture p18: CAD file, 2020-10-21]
Mechanical Design/manf/rocketPadConnectorBottom.STL
106.6 x 65.0 x 106.6

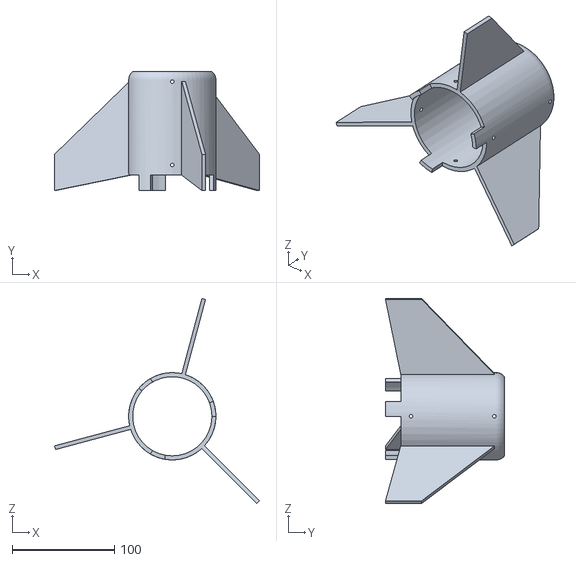
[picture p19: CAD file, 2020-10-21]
Mechanical Design/manf/rocketPadConnectorTopFins.STL
200.7 x 116.6 x 200.7

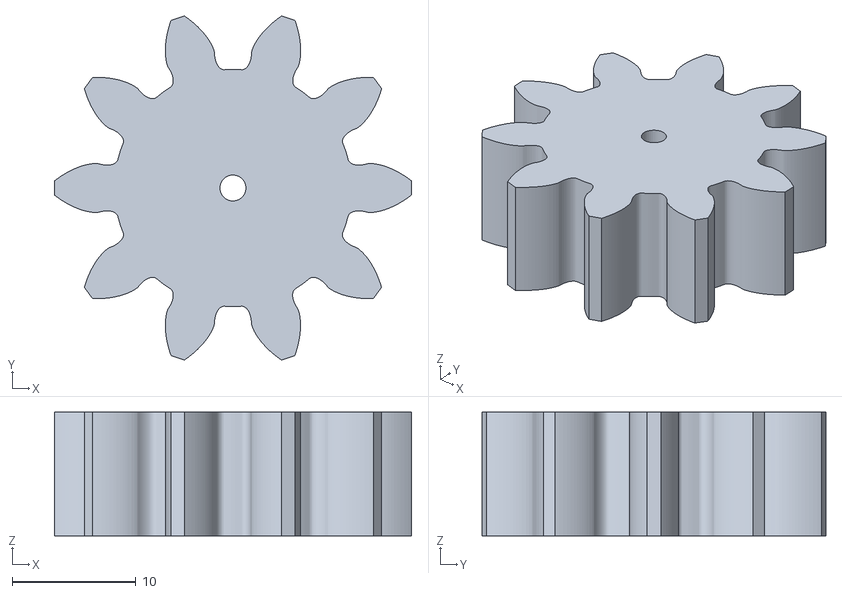
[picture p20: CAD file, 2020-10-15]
Mechanical Design/guidanceComputerMount/gear/gear1-90.STL
28.9 x 27.8 x 10.0

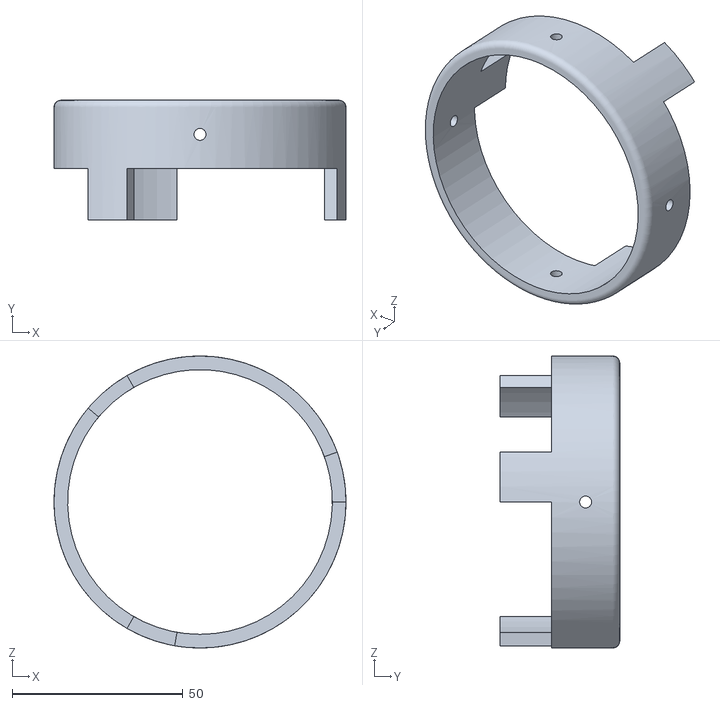
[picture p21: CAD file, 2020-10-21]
Mechanical Design/manf/rocketPadConnectorTop.STL
85.5 x 35.0 x 85.5

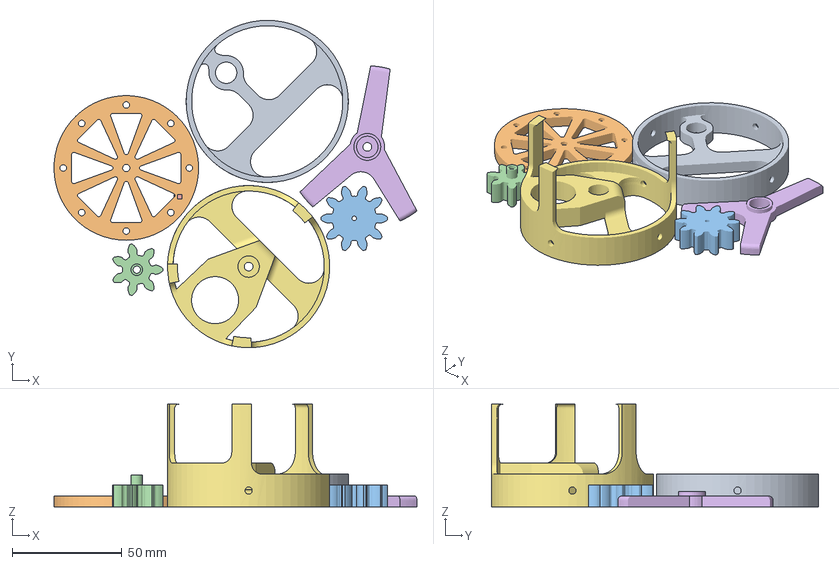
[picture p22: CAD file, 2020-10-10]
Mechanical Design/manf/all roll stuff.3mf
165.7 x 149.4 x 47.0 mm
guidance mount bottom.STL
rollwheeeel.STL
gear1.STL
gear2.STL
clampingSpacer.STL
topMountP2v3.STL
topMountP1v3.STL

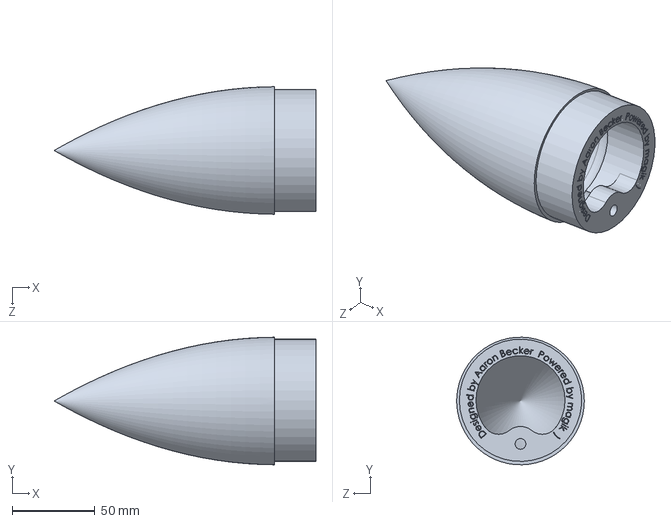
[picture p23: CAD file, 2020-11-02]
Mechanical Design/nosecone.SLDPRT
158.1 x 77.0 x 77.0 mm

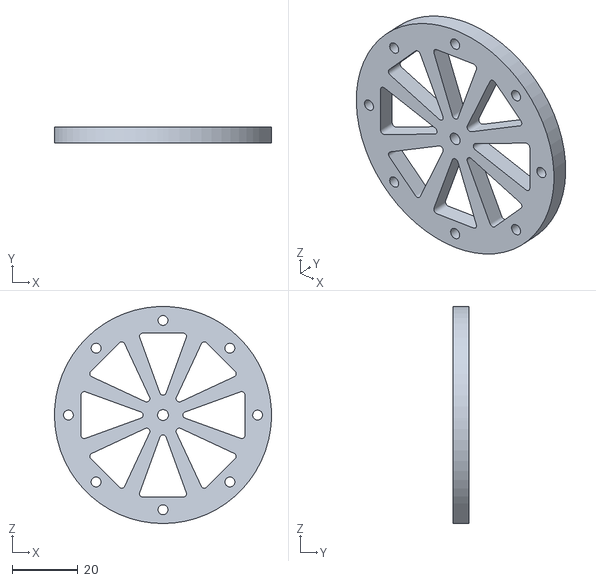
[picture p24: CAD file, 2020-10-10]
Mechanical Design/manf/rollwheeeel.STL
66.0 x 5.00 x 66.0

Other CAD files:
Mechanical Design/guidanceComputerMount/gear/gear2-90.STL
Mechanical Design/guidanceComputerMount/gear2.SLDPRT
Mechanical Design/guidanceComputerMount/gear/gear1-95.STL
Mechanical Design/guidanceComputerMount/gear1.SLDPRT
Mechanical Design/FIXME piston bulkhead.SLDPRT
Mechanical Design/body tube bottom.SLDPRT
Mechanical Design/body tube top.SLDPRT
Mechanical Design/controllerBox/box.STL
Mechanical Design/coupler.SLDPRT
Mechanical Design/gimbalInner.SLDPRT
Mechanical Design/gimbalOuter.SLDPRT
Mechanical Design/gimbalOutside.SLDPRT
Mechanical Design/guidanceComputerMount/1327K930_MINIATURE 12L14 DRIVE STEEL SHAFT.SLDPRT
Mechanical Design/guidanceComputerMount/57155K207_STAINLESS STEEL BALL BEARING.SLDPRT
Mechanical Design/guidanceComputerMount/9414T300_SET SCREW SHAFT COLLAR.SLDPRT
Mechanical Design/guidanceComputerMount/antenna.SLDPRT
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

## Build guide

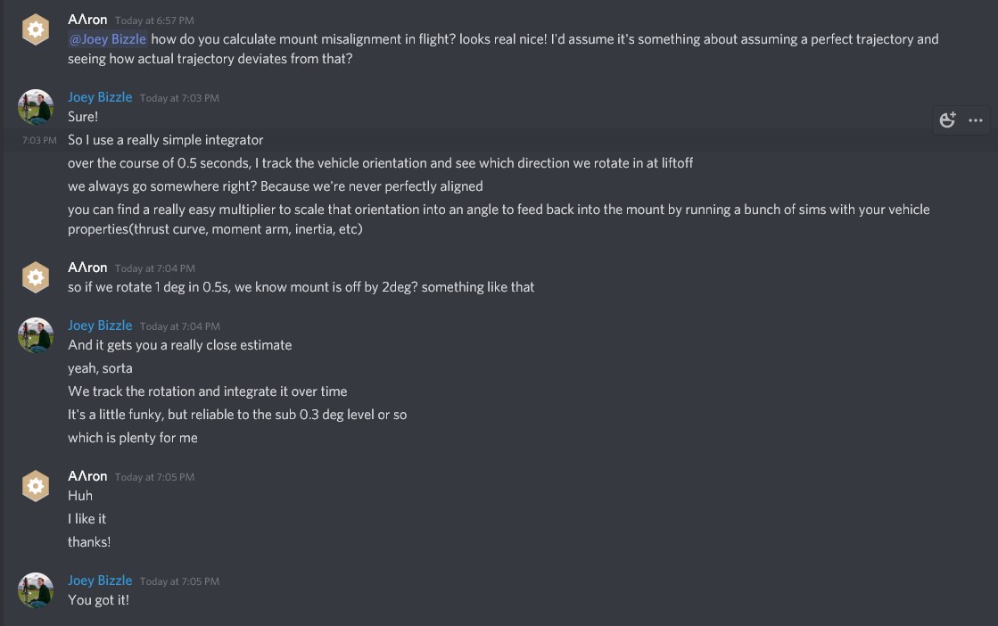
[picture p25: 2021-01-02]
Software/Reference/how to calc mount misalighment.jpg

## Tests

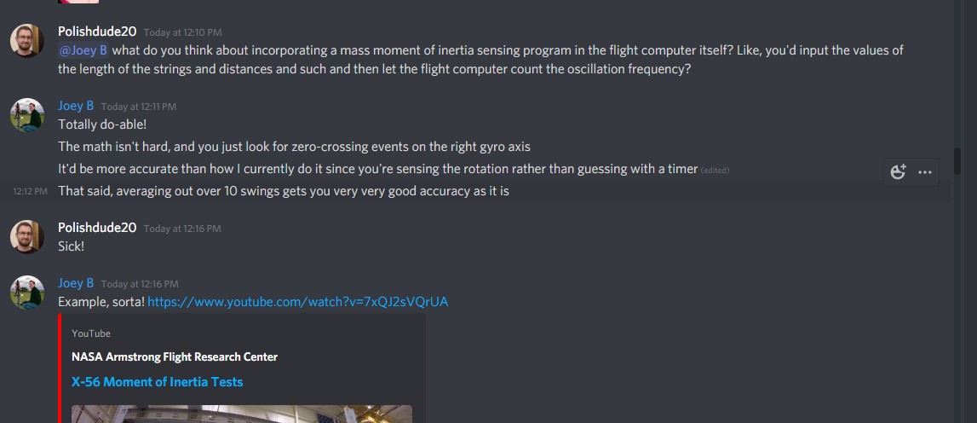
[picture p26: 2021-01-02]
Software/Reference/mmoi calibration program.jpg

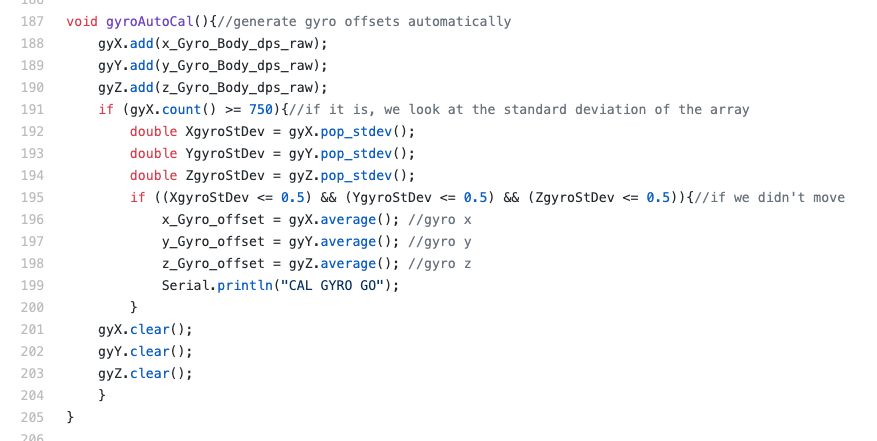
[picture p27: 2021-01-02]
Software/Reference/joe's gyro auto calibration code (robtilaart statistic lib).png

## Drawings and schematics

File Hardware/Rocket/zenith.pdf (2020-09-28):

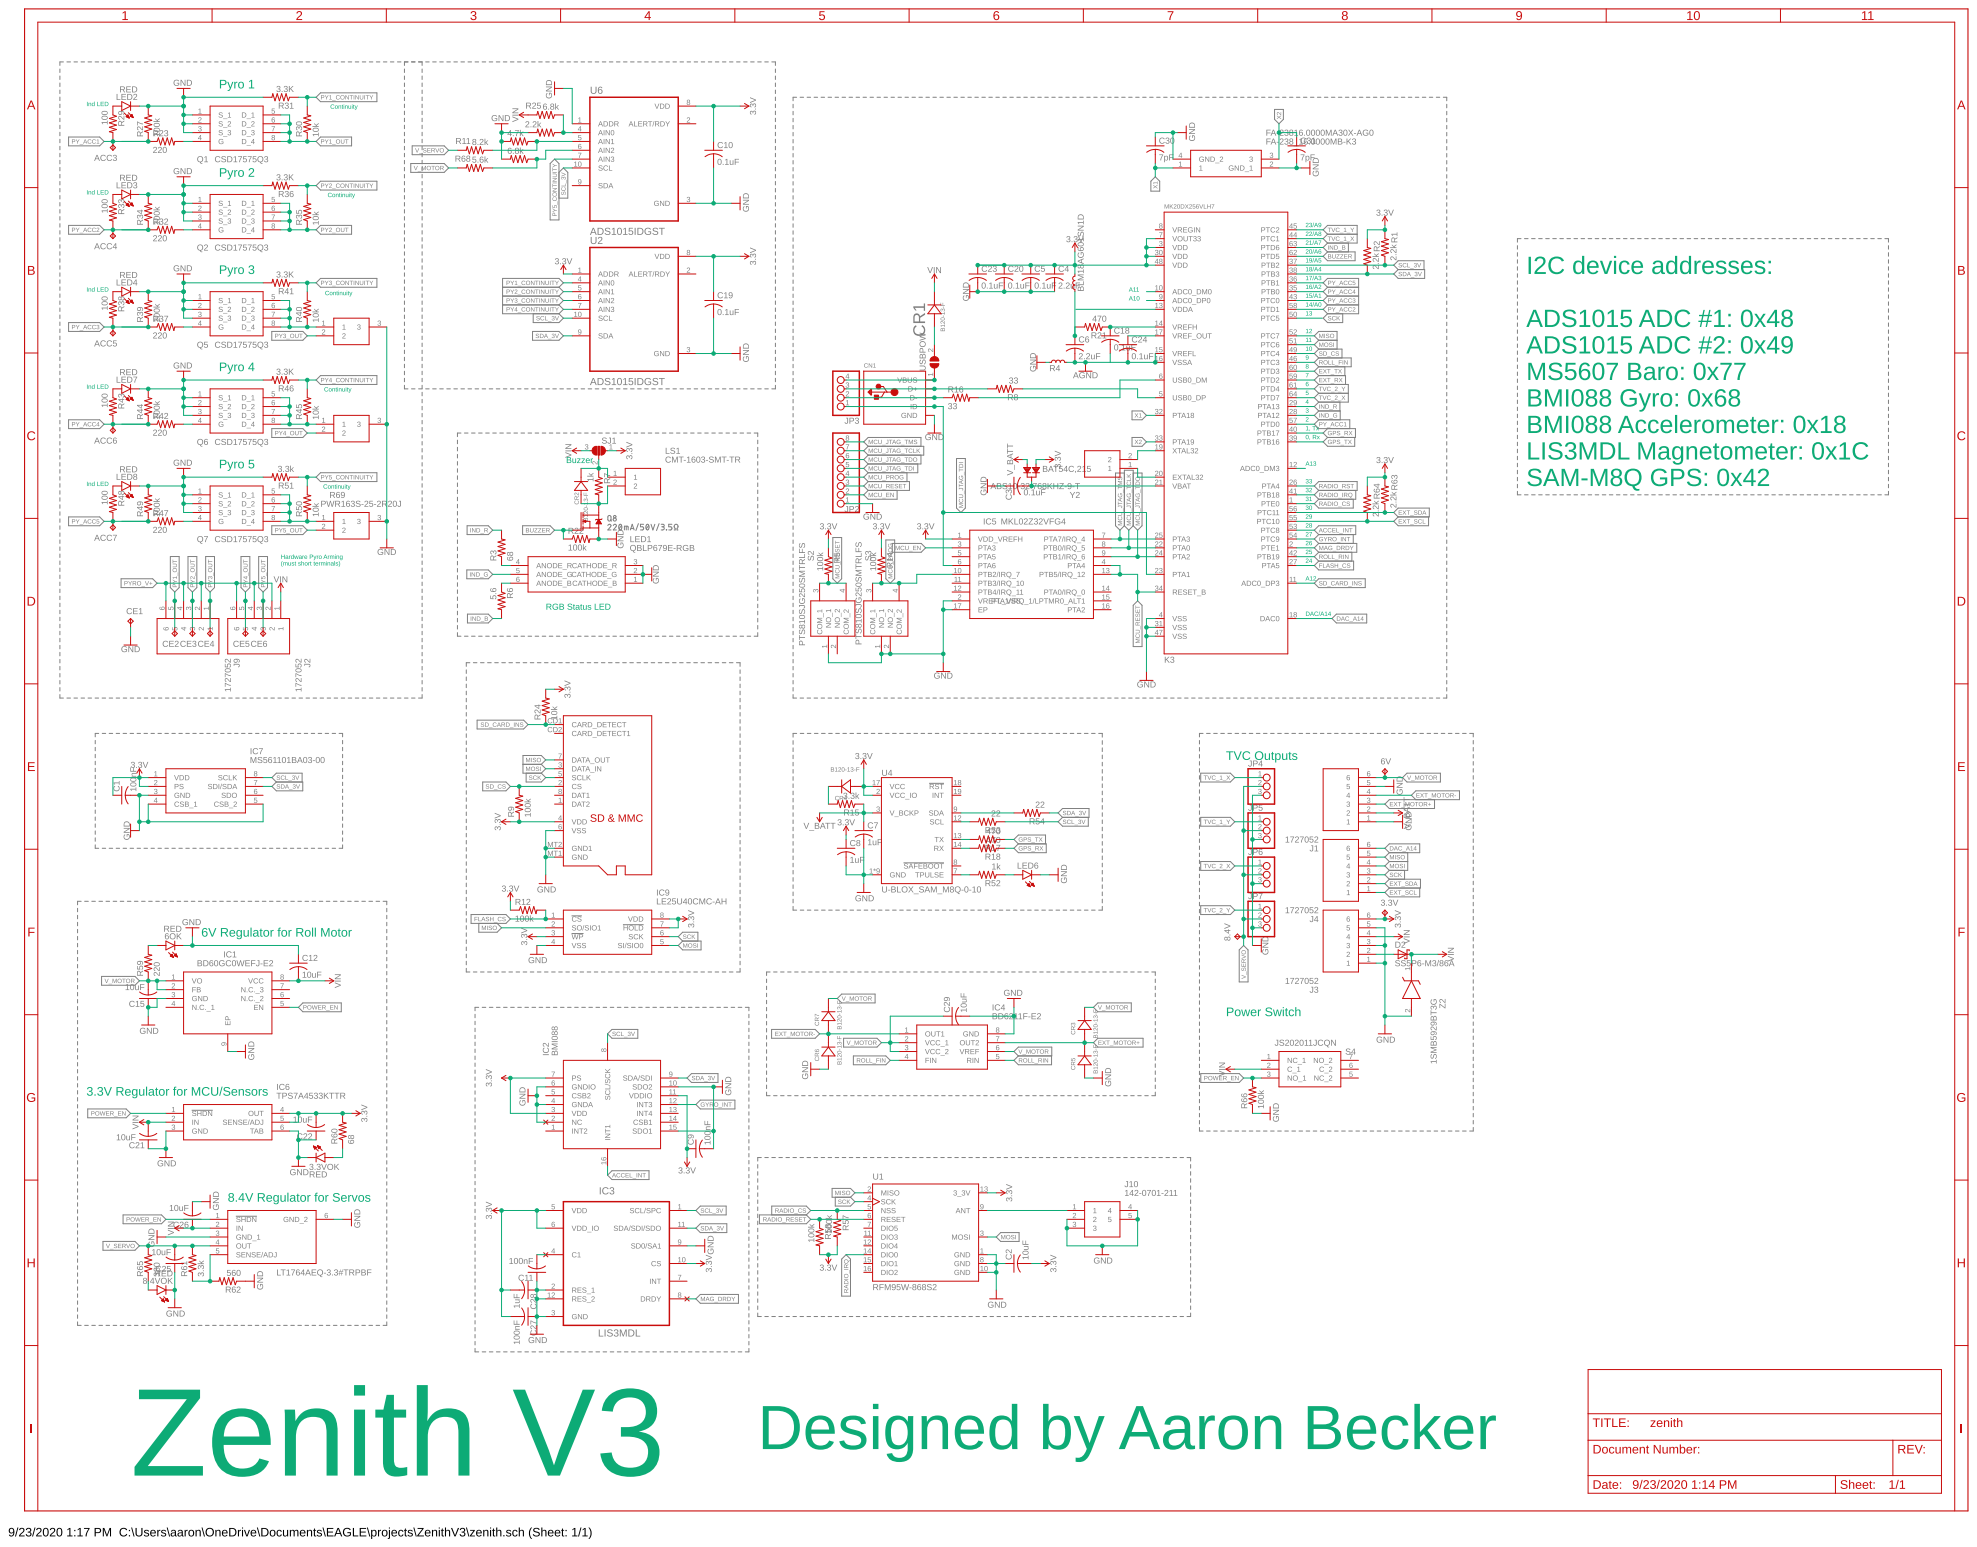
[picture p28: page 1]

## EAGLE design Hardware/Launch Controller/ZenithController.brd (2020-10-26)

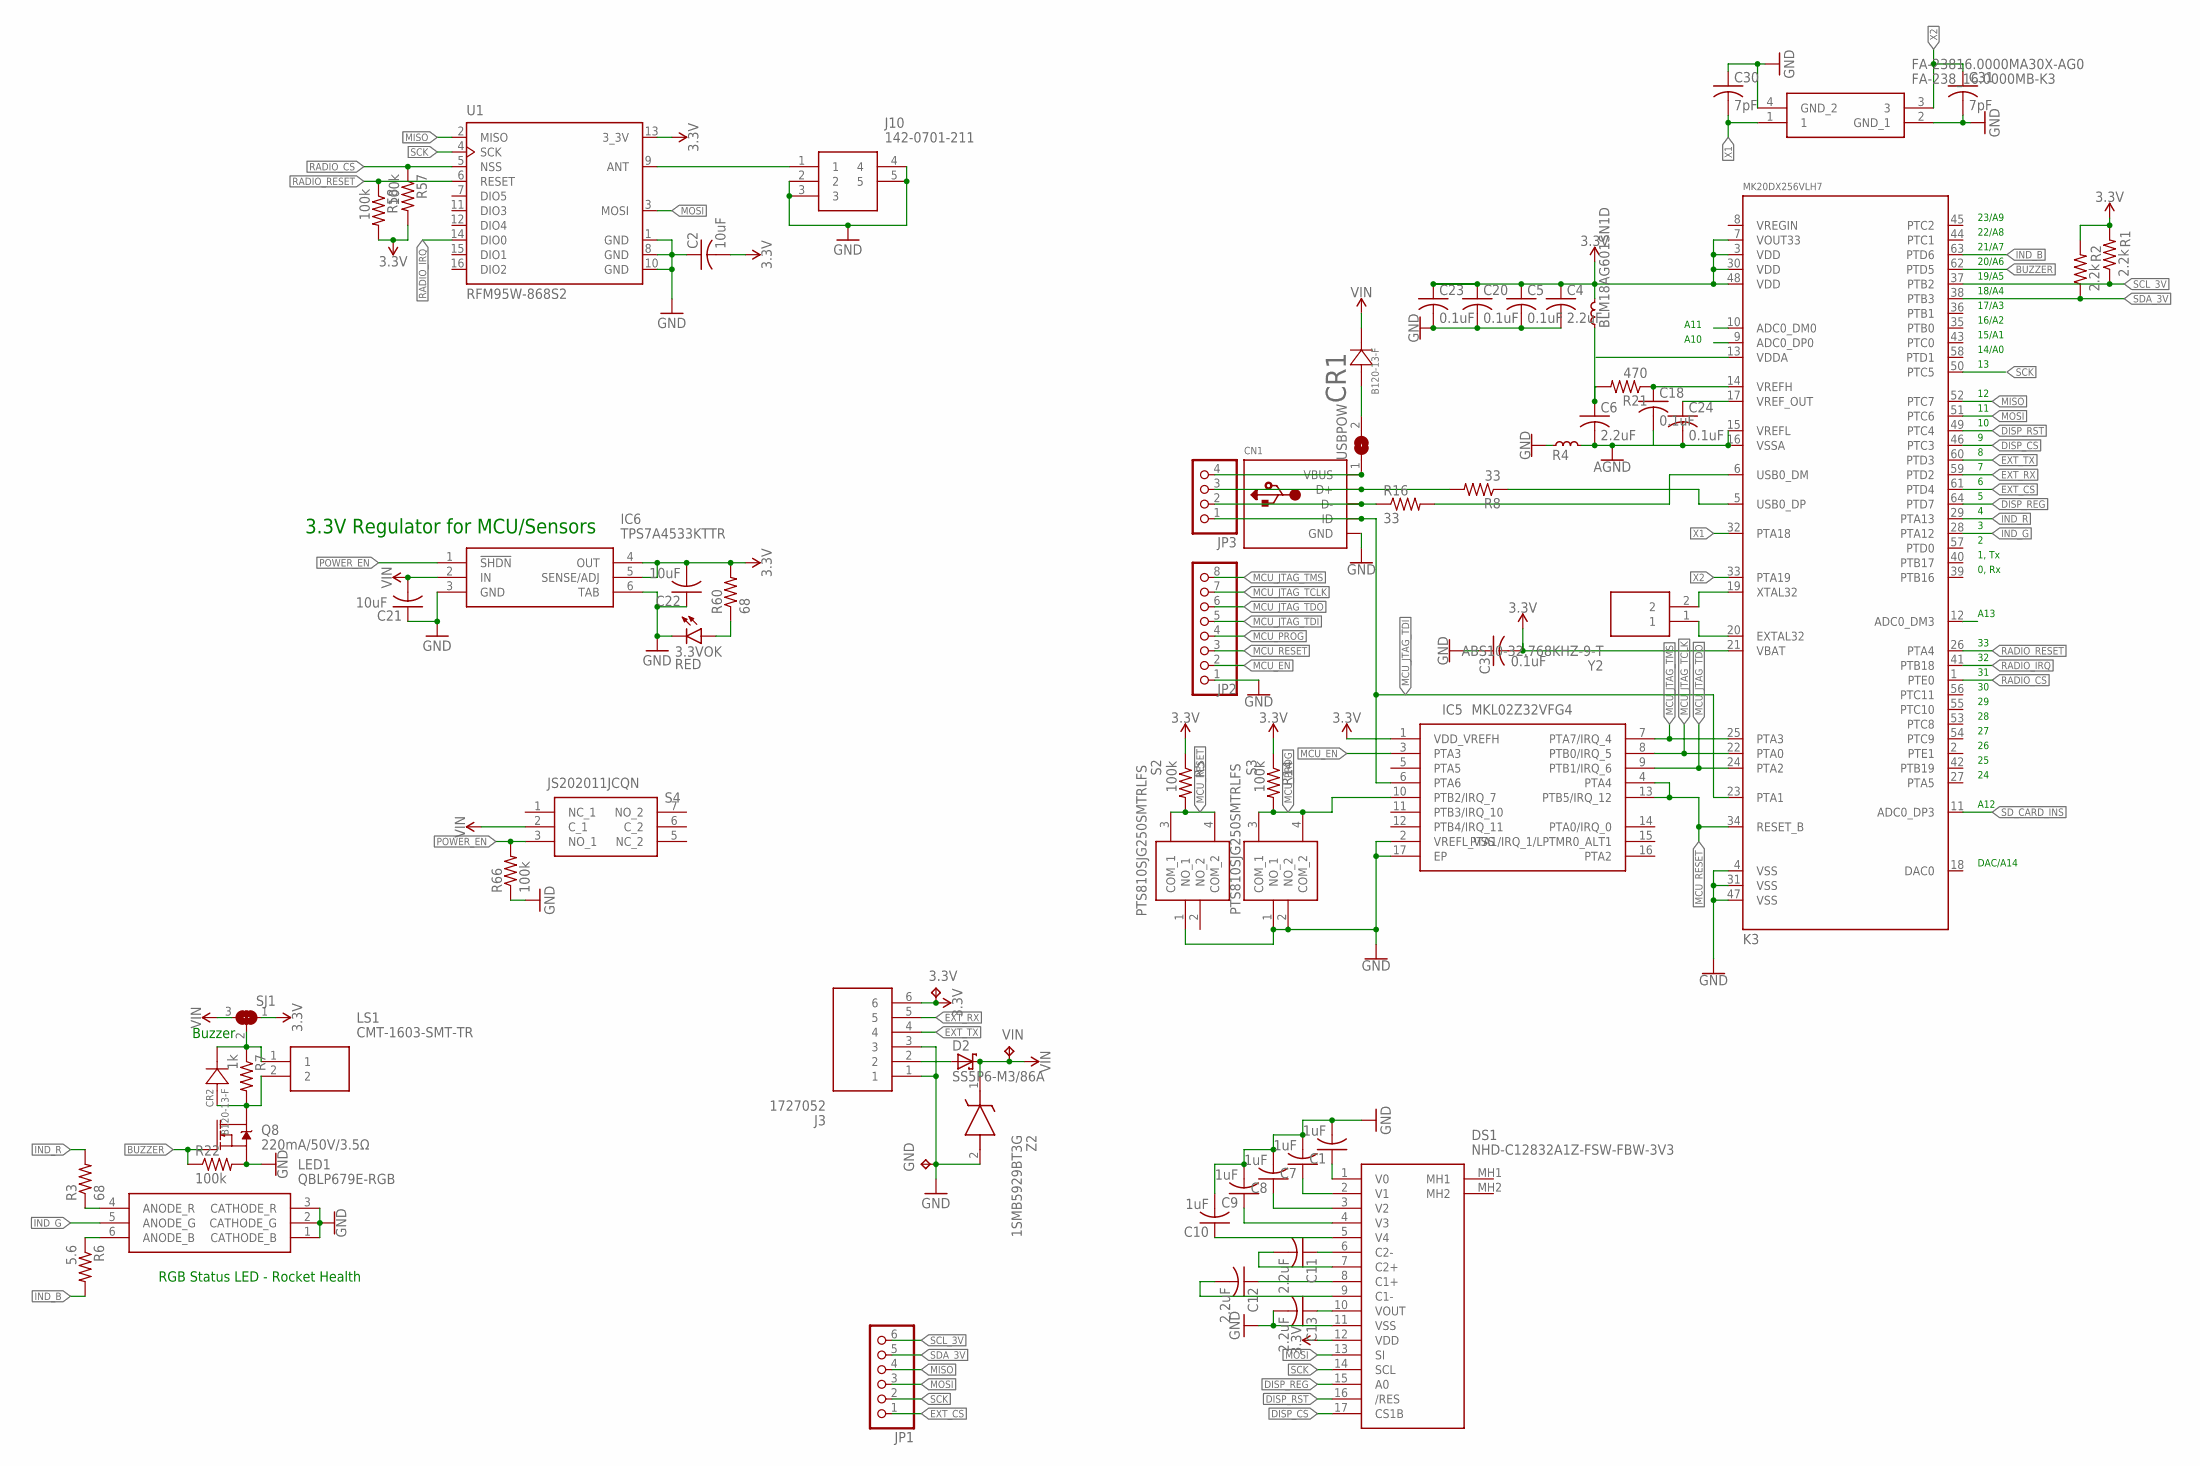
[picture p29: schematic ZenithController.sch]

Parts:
3.3V: TPB1,27; B1,27
3.3VOK: RED; CHIP-LED0805
BLM18AG601SN1D: FERRITE; L0603
C1, C7, C8, C9, C10: 1uF; C0603
C2, C21, C22: 10uF; C0603
C3, C5, C18, C20, C23, C24: 0.1uF; C0603
C4, C6, C11, C12, C13: 2.2uF; C0603
C30, C31: 7pF; C0603
CN1: USBMINIB; USB-MINIB
CR1, CR2: B120-13-F; SMA_DIO
D2: SS5P6-M3/86A; TO-277A(SMPC)
DS1: NHD-C12832A1Z-FSW-FBW-3V3; NHDC12832A1ZFSWFBW3V3
FA-23816.0000MA30X-AG0: FA-238_16.0000MB-K3; EPSON-FA-238
GND: TPB1,27; B1,27
IC5: MKL02Z32VFG4; QFN50P300X300X65-17N
IC6: TPS7A4533KTTR; KTT0005B
J3: 1727052; SHDR6W105P0X381_1X6_2285X730X8
J10: 142-0701-211; 1420701211
JP1: PINHD-1X6; 1X06
JP2: PINHD-1X8; 1X08
JP3: PINHD-1X4; 1X04
K3: MK20DX256VLH7; LQFP64-05
LED1: QBLP679E-RGB; QBLP679ERGB
LS1: CMT-1603-SMT-TR; CMT1603SMTTR
Q8: 220mA/50V/3.5Ω; SOT23-3
R1, R2: 2.2k; R0603
R3, R60: 68; R0603
R4: FERRITE; L0603
R5, R14, R22, R57, R58, R66: 100k; R0603
R6: 5.6; R0603
R7: 1k; R0603
R8, R16: 33; R0603
R21: 470; R0603
S2, S3: PTS810SJG250SMTRLFS
S4: JS202011JCQN
SJ1: SOLDERJUMPER_2WAY0603; SOLDERJUMPER_2WAY_OPEN_0603
U1: RFM95W-868S2; XCVR_RFM95W-868S2
USBPOW: SJ
VIN: TPB1,27; B1,27
Y2: ABS10-32.768KHZ-9-T; ABS-10
Z2: 1SMB5929BT3G; DIOM5436X247N

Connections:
3.3V: 3.3V.TP, BLM18AG601SN1D.2, C2.2, C3.2, C4.1, C5.1, C20.1, C22.2, C23.1, DS1.12 (VDD), IC5.1 (VDD_VREFH), IC6.4 (OUT), IC6.5 (SENSE/ADJ), J3.6, K3.3 (VDD), K3.7 (VOUT33), K3.21 (VBAT), K3.30 (VDD), K3.48 (VDD), R1.2, R2.2, R5.1, R14.1, R57.2, R58.2, R60.2, SJ1.1, U1.13 (3_3V)
AGND: C6.2, C18.2, C24.2, K3.15 (VREFL), K3.16 (VSSA), R4.2
BUZZER: K3.62 (PTD5), Q8.1 (G), R22.1
DISP_CS: DS1.17 (CS1B), K3.46 (PTC3)
DISP_REG: DS1.15 (A0), K3.64 (PTD7)
DISP_RST: DS1.16 (/RES), K3.49 (PTC4)
EXT_CS: JP1.1, K3.61 (PTD4)
EXT_RX: J3.5, K3.59 (PTD2)
EXT_TX: J3.4, K3.60 (PTD3)
GND: 3.3VOK.C, C1.2, C2.1, C3.1, C4.2, C5.2, C7.2, C8.2, C9.2, C10.2, C13.2, C20.2, C21.1, C22.1, C23.2, C30.1, C31.2, CN1.GND, DS1.11 (VSS), FA-23816.0000MA30X-AG0.2 (GND_1), FA-23816.0000MA30X-AG0.4 (GND_2), GND.TP, IC5.2 (VREFL_VSS), IC5.17 (EP), IC6.3 (GND), IC6.6 (TAB), J3.1, J3.3, J10.2, J10.3, J10.4, J10.5, JP2.1, K3.4 (VSS), K3.31 (VSS), K3.47 (VSS), LED1.1 (CATHODE_B), LED1.2 (CATHODE_G), LED1.3 (CATHODE_R), Q8.2 (S), R4.1, R22.2, R66.1, S2.1 (NO_1), S3.1 (NO_1), S3.2 (NO_2), U1.1 (GND), U1.8 (GND), U1.10 (GND), Z2.2 (A)
IND_B: K3.63 (PTD6), R6.2
IND_G: K3.28 (PTA12), LED1.5 (ANODE_G)
IND_R: K3.29 (PTA13), R3.2
MCU_EN: IC5.3 (PTA3), JP2.2
MCU_JTAG_TCLK: IC5.8 (PTB0/IRQ_5), JP2.7, K3.22 (PTA0)
MCU_JTAG_TDI: CN1.ID, IC5.6 (PTA6), JP2.5, JP3.1, K3.23 (PTA1)
MCU_JTAG_TDO: IC5.9 (PTB1/IRQ_6), JP2.6, K3.24 (PTA2)
MCU_JTAG_TMS: IC5.7 (PTA7/IRQ_4), JP2.8, K3.25 (PTA3)
MCU_PROG: IC5.10 (PTB2/IRQ_7), JP2.4, R14.2, S3.3 (COM_1), S3.4 (COM_2)
MCU_RESET: IC5.4 (PTA4), IC5.13 (PTB5/IRQ_12), JP2.3, K3.34 (RESET_B), R5.2, S2.3 (COM_1), S2.4 (COM_2)
MISO: JP1.4, K3.52 (PTC7), U1.2 (MISO)
MOSI: DS1.13 (SI), JP1.3, K3.51 (PTC6), U1.3 (MOSI)
unnamed: C1.1, DS1.1 (V0)
unnamed: LED1.4 (ANODE_R), R3.1
unnamed: K3.19 (XTAL32), Y2.2
unnamed: BLM18AG601SN1D.1, C6.1, R21.2
unnamed: C7.1, DS1.2 (V1)
unnamed: LED1.6 (ANODE_B), R6.1
unnamed: CR2.2, LS1.2, Q8.3 (D), R7.2
unnamed: J10.1, U1.9 (ANT)
unnamed: C8.1, DS1.3 (V2)
unnamed: C24.1, K3.17 (VREF_OUT)
unnamed: 3.3VOK.A, R60.1
unnamed: C9.1, DS1.4 (V3)
unnamed: C10.1, DS1.5 (V4)
unnamed: C13.1, DS1.10 (VOUT)
unnamed: C11.1, DS1.6 (C2-)
unnamed: C11.2, DS1.7 (C2+)
unnamed: C12.1, DS1.8 (C1+)
unnamed: C12.2, DS1.9 (C1-)
unnamed: CN1.D+, JP3.3, R8.2
unnamed: CN1.D-, JP3.2, R16.1
unnamed: K3.5 (USB0_DP), R8.1
unnamed: K3.6 (USB0_DM), R16.2
unnamed: CR1.2, USBPOW.2
unnamed: CN1.VBUS, JP3.4, USBPOW.1
unnamed: C18.1, K3.14 (VREFH), R21.1
unnamed: CR2.1, LS1.1, R7.1, SJ1.2
unnamed: D2.A1 (A), D2.A2 (A), J3.2
unnamed: K3.20 (EXTAL32), Y2.1
POWER_EN: IC6.1 (!SHDN), R66.2, S4.3 (NO_1)
RADIO_CS: K3.1 (PTE0), R57.1, U1.5 (NSS)
RADIO_IRQ: K3.41 (PTB18), U1.14 (DIO0)
RADIO_RESET: K3.26 (PTA4), R58.1, U1.6 (RESET)
SCK: DS1.14 (SCL), JP1.2, K3.50 (PTC5), U1.4 (SCK)
SCL_3V: JP1.6, K3.37 (PTB2), R1.1
SDA_3V: JP1.5, K3.38 (PTB3), R2.1
SD_CARD_INS: K3.11 (ADC0_DP3)
VIN: C21.2, CR1.1, D2.K (C), IC6.2 (IN), S4.2 (C_1), SJ1.3, VIN.TP, Z2.1 (K)
X1: C30.2, FA-23816.0000MA30X-AG0.1, K3.32 (PTA18)
X2: C31.1, FA-23816.0000MA30X-AG0.3, K3.33 (PTA19)

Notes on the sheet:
23/A9
22/A8
21/A7
20/A6
19/A5
18/A4
17/A3
16/A2
15/A1
14/A0
1, Tx
0, Rx
A13
A12
DAC/A14
A11
A10
3.3V Regulator for MCU/Sensors
Buzzer
RGB Status LED - Rocket Health

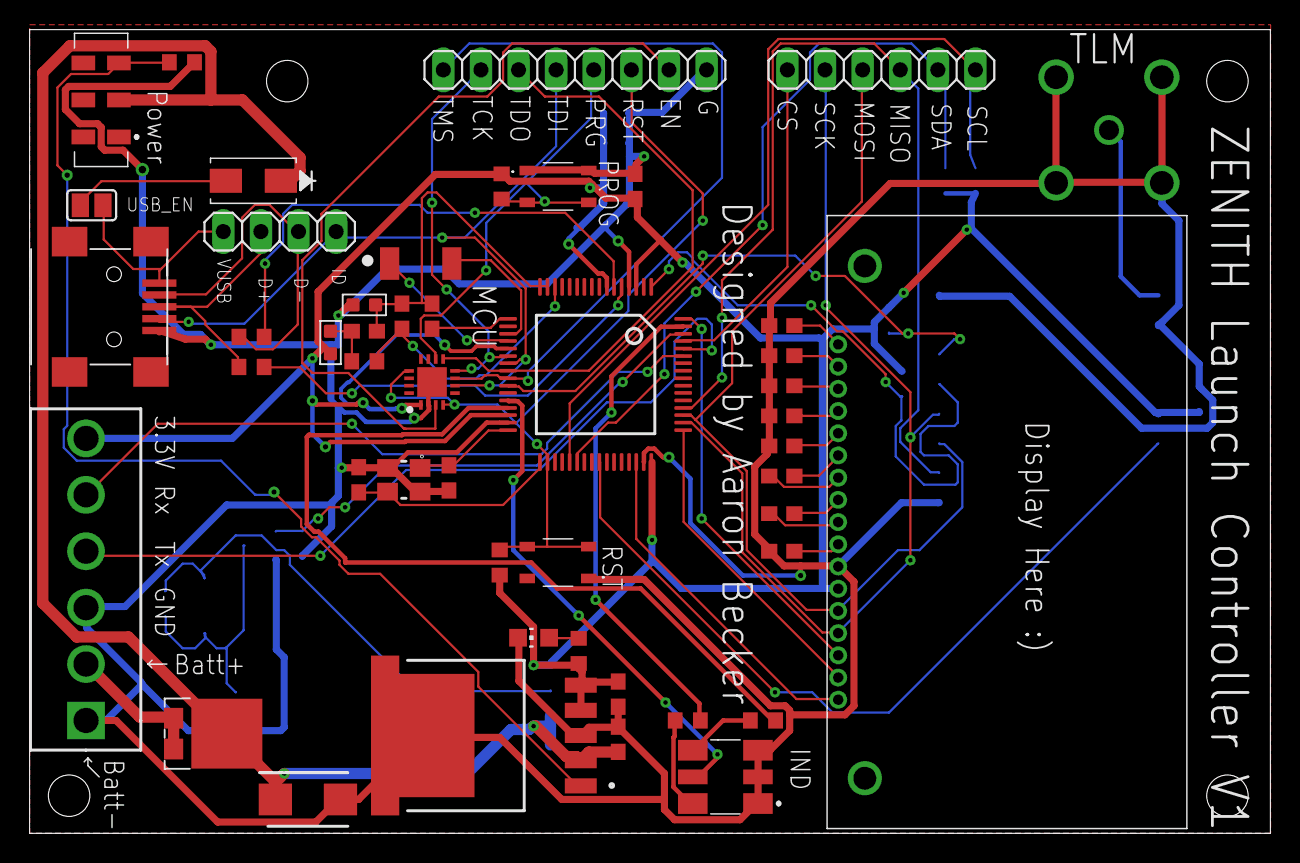
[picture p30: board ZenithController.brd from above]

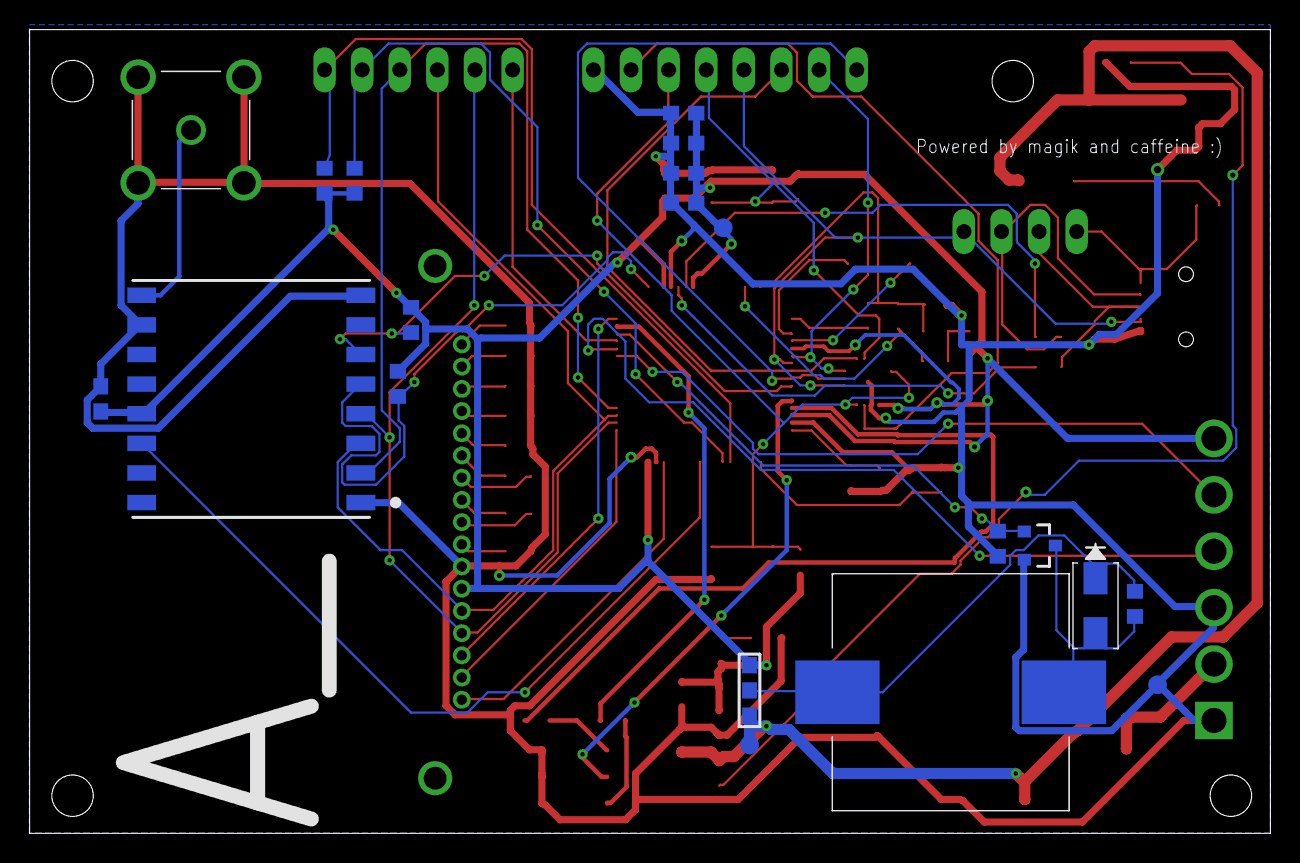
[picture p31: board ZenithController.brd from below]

Board: 2 copper layers, 83.8 x 54.3 mm, 67 parts (20 on the bottom side), 60 nets.

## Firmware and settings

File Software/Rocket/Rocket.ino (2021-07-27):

/*
By Aaron Becker

rocket notes:

- write page of flash using struct
- USE i2c for 
- kalman filter - really high acceleration events - throw out bad data

Sensor List

IMU: BMI088

ms5611 https://github.com/jarzebski/Arduino-MS5611
new antenna https://www.videoaerialsystems.com/products/868-900mhz-longshot-antenna


update todo notes:
2nd adc support

buzzer enum state
tvc enabled enum state
fix odd bug with lastRadioRecievedTimer and state changed based on telconn state


Thrust curve interpolation
https://github.com/luisllamasbinaburo/Arduino-Interpolation

JOE FULL TELEMETRY
https://docs.google.com/spreadsheets/d/1g16lZlNKqRVAd4mePxDKsWFw7Lo1jOPMTm628585Fh4/edit#gid=2054543638

things to check before go to ready state (from startup):
- good GPS lock
- low PDOP
- real lat/lon data (constrained)
- battery
- 5-6 other things in gps alone



self test where rocket checks the following:
- rail voltages ok
- batt v within range
- pyro continuous vs short detect - make sure not shorted

TODOS:
make constant for servo angle to tvc mount angle and test accuracy
potential for PWM resolution changing? https://www.pjrc.com/teensy/td_pulse.html
use high grav/low grav accelerometer - when over 7g, flip measurements over to high g accelerometer
On startup, check flash chip for any data that was left on it and dump to SD


ori stuff
1) start in calibrate mode on pad
2) complementary filter while on pad
3) zero roll and PID I value right before launch
4) launch go gyro only
Also use interrupts for sensor

Everything that joe is logging that I should as well:
ones that make sense:
- avi voltage
- data error flag
- nav error flag
- abort state flag
- py 1-5 continuity
- py 1-5 fire
- vehicle mass (lin approx)
- flight time in sec
- baro alt (long avg)
- tvc y, z error
- Leg deployment
- landing abort status
- Ejection progress (multi step)
- ejection success
- fin deployment state
- bleed-off percent
- divert altitude error
- divert altitude height
- max height
- target burn alt
- GNSS y, x vel
- Acc z, y
- gyro x, y, z
- predicted ori for landing z, y
- fused ori x, y, z
- ori setpoints
- roll wheel setpoint
- tvc torque z, y
- baro pressure
- max alt
- gnss pdop
- gnss fix type (3d, etc)
- gnss sat count (SIV)
- raw pressure
- fused pos x, y, z
- fused vel x, y, z
- active accel biasing x, y, z
- velocity bias? x, y, z
- ori bias? x, y, z
- tvc setpoint y, z
- board temp
- system state
- flight time
- gain set 1-5: different guidance modes (trying to control position when rising, velocity at the very end)

ones that I'm not sure what they are:
- gyro_yi seems to be a backup gyroscope possibly
- difference between gyro_yi_sp, gyro_yi_s, gyro_yb_sp_s (sp = setpoint?)
1hz outside of flight, 50hz in flight

i = intertial frame (global, up and down is relative to gravity)
b = body frame (body, relative to vehicle)
move from inertial to body to remove effect of roll

Cool things joey b does:
use torque based controller w/  mass, mass moment of inertia, COM to come up with a more accurate TVC scheme
use max alt and simulated motor ignition to come up with burn altitude for landing (monte carlo sim in lookup table probably)
use more simulation to know where the vehicle "should be" based on Cd after landing ignition, calculate divert altitude to start divert movement
use divert altitude error (error from the vehicle's should be calculation to where it actually is) to come up with bleed percent (peak amplitude of sin wave divert)
can calculate bleed percent with 100-motorthrust*cos(mountangle) = bleed percent
landing burn commit: can light landing motor outside of abort limits as long as vehicle is on track to enter abort limits (predict from gyro rate and current ori)

if(micros() < lastMicros) weRolledOver();
Micros rollover count

https://github.com/n0m1/Comp6DOF_n0m1
Compass tilt calibration

*/


//TODOS GPS, SD

//External libs
#include <SPI.h>
#include <Wire.h>
#include <SD.h>
#include "libs/ADS1X15/ADS1X15.cpp"
#include <Servo.h>
#include <RH_RF95.h>
#include "libs/PID/pid.cpp"
#include "libs/BMI088/BMI088.cpp"
#include "libs/Orientation/Quaternion.cpp"
#include "libs/Orientation/Orientation.cpp"
#include "libs/MS5611/MS5611.cpp"
#include "libs/Ublox/SparkFun_Ublox_Arduino_Library.cpp"
#include <SPIMemory.h>
#include "math.h"

//Internal header files
#include "states.h"
#include "pindefs.h"
#include "constants.h"

/*
DEBUG
*/

//#define DEBUG


#ifdef DEBUG
	#define debugPrintln(x)  Serial.println (x)
	#define debugPrint(x)  Serial.print(x)
	#include "printf.h"
	const boolean debug = true;
#else
	#define debugPrint(x)
	#define debugPrintln(x)
	const boolean debug = false;
#endif

/*
FLIGHT MODE ENUMS
*/
FlightMode flightMode = BOOTING;
PyroStates pyroState = PY_DISARMED;
ChuteStates chuteState = C_DISARMED;
DataLoggingStates dataLoggingState = DL_ENABLED_5HZ;
TelemSendStates telemetryState = TEL_ENABLED_30HZ;
TelemConnStates telemetryConnectionState = TEL_DISCONNECTED;
TVCEnabledMode tvcEnabled = TVC_DISABLED;
OriMode oriMode = INIT;

/*
RADIO
*/
RH_RF95 radio(RADIO_CS, RADIO_IRQ);

struct RadioPacket {
	uint8_t id;
	int data1;
	int data2;
	int data3;
};

/*
Radio Command List
0: Ping/pong check (heartbeat)
1: SetRocketState
2: RequestRocketTelem
3: Enable/Disable Pyros
4: FirePyro
*/

typedef enum {
	HEARTBEAT = 0,
	SETSTATE = 1,
	REQTELEM = 2,
	PYROARMING = 3,
	FIREPYRO = 4
} RadioCommands;

const int radioTimeoutDelay = 5000;
unsigned long lastRadioRecieveTime = 0;

/*
TELEMETRY STRUCT
*/
/*
	data-raw-gyro -> gyro data
	data-raw-accel => accel data
	data-ori => orientation fused frame data
	data-pos => XYZ position (xPos, yPos, zPos, time) with xPos being vertical position (altitude)
	data-vel => XYZ velocity (xVel, yVel, zVel, time) with xVel being vertical velocity

	v-connect => vehicle has connected, start VOT timer
	v-disconnect => vehicle has disconnected, stop VOT timer
	DONE t-connect => arduino transmitter is connected
	DONE t-disconnect => arduino transitter disconnected
	vot-set => set vehicle on time forcefully in ms (vot)
	met-set => set mission elapsed time forcefully in ms (met)
	m-start => mission started, start MET timer
	v-stop => mission stopped, stop MET timer

	v-tvc => tvc update (y, z, active, rollPercent, rollSetpoint, twr, mass)

	v-state => various state things (battV, rollV, servoV, vehicleState, pyroState, temp, signal, tlmRate, fixType, pDOP, horizAcc, vertAcc, gpsSats)
*/

struct TELEMETRY {
	//Raw vehicle information
	unsigned long timeSinceStartup;
	unsigned long missionElapsedTime;

	//State stuff
	FlightMode fMode;
	PyroStates pState;
	ChuteStates cState;
	DataLoggingStates dState;
	TelemSendStates tSState;
	TelemConnStates tCState;

	//Basic sensor data
	float battV;
	float servoV;
	float rollMotorV;
	float boardTemp;

	//Raw sensor data
	double gyroX;
	double gyroY;
	double gyroZ;
	double accX;
	double accY;
	double accZ;
	long GNSSLat;
	long GNSSLon;

	//Calculated state vector data
	double oriX;
	double oriY;
	double oriZ;
	double posX;
	double posY;
	double posZ;
	double velX;
	double velY;
	double velZ;

	//TVC Data
	double tvcY;
	double tvcZ;
	bool tvcActive;

	//Roll wheel data
	float rollPercent;
	float rollSetpoint;

	//Vehicle estimation
	float twr;
	float mass;
	
	//GNSS locking data
	byte GNSSFix;
	int GNSSpDOP;
	byte GNSSSats;
	int GNSSAccHoriz; //mm
	int GNSSAccVert; //mm
	int GNSSAccVel; //mm

	//Pyro channel data
	bool pyro1Cont;
	bool pyro2Cont;
	bool pyro3Cont;
	bool pyro4Cont;
	bool pyro5Cont;
	bool pyro1Fire;
	bool pyro2Fire;
	bool pyro3Fire;
	bool pyro4Fire;
	bool pyro5Fire;
};
struct TELEMETRY telem;

unsigned long lastTelem = 0;

/*
ADC CONFIG
*/

ADS1015 ADS1(ADC1_I2C_ADDR);
ADS1015 ADS2(ADC2_I2C_ADDR);

/*
GYRO/ACCELEROMETER SETUP
*/
Bmi088Accel accel(Wire,ACC_I2C_ADDR);
Bmi088Gyro gyro(Wire,GYRO_I2C_ADDR);

/*
MS5611 BAROMETER CONFIG
*/
MS5611 ms5611;

/*
GNSS
*/

SFE_UBLOX_GPS GPS;

/*
FLASH MEMORY
*/
SPIFlash flash(FLASH_CS);

/*
SD CARD
*/
char dataLogFilename[13];

/*
BUZZER CONFIG
*/

unsigned long lastBuzzer = 0;
int buzzerDelay = 1000;

const byte toneBufferLength = 20;
int toneFreqQueue[toneBufferLength];
int toneDelayQueue[toneBufferLength];
unsigned long lastToneStart = 0;
byte toneStackPos = 0;

/*
LED CONFIG
*/

unsigned long lastLED = 0;
int LEDDelay = 1000;

const byte ledBufferLength = 20;
int ledRQueue[ledBufferLength];
int ledGQueue[ledBufferLength];
int ledBQueue[ledBufferLength];
int ledDelayQueue[ledBufferLength];
unsigned long lastLEDStart = 0;
byte ledStackPos = 0;

/*
PYRO CHANNEL CONFIG
*/

unsigned long pyroOffTimes[5];
bool pyroStates[5];
int pyrosInUse = 0;

/*
TVC SERVOS CONFIG
*/
Servo TVC_X_CH1;
Servo TVC_Y_CH1;
Servo TVC_X_CH2;
Servo TVC_Y_CH2;

PID zAxis(PID_Z_P, PID_Z_I, PID_Z_D, 0);
PID yAxis(PID_Y_P, PID_Y_I, PID_Y_D, 0);


/*
MISC VARS
*/
unsigned long lastSensorUpdate = 0;
const int sensorUpdateDelay = 200;

bool gyro_ready = false;
bool accel_ready = false;

void gyro_drdy() {
	gyro_ready = true;
}
void accel_drdy() {
	accel_ready = true;
}

void setup() {	
	//Setup pin states
	pinMode(IND_R_PIN, OUTPUT);
	pinMode(IND_G_PIN, OUTPUT);
	pinMode(IND_B_PIN, OUTPUT);
	pinMode(BUZZER_PIN, OUTPUT);

	pinMode(PYRO1_PIN, OUTPUT);
	pinMode(PYRO2_PIN, OUTPUT);
	pinMode(PYRO3_PIN, OUTPUT);
	pinMode(PYRO4_PIN, OUTPUT);
	pinMode(PYRO5_PIN, OUTPUT);

	pinMode(TVC_X_CH1_PIN, OUTPUT);
	pinMode(TVC_Y_CH1_PIN, OUTPUT);
	pinMode(TVC_X_CH2_PIN, OUTPUT);
	pinMode(TVC_Y_CH2_PIN, OUTPUT);

	pinMode(ROLL_FIN, OUTPUT);
	pinMode(ROLL_RIN, OUTPUT);

	pinMode(SD_INS, INPUT);
	//Note: do not use pinMode on any of the SPI pins otherwise stuff doesn't work!

	//TVC Setup
	TVC_X_CH1.attach(TVC_X_CH1_PIN, SERVO_MIN_US, SERVO_MAX_US); //Attach all servos to their respective pins
	TVC_Y_CH1.attach(TVC_Y_CH1_PIN, SERVO_MIN_US, SERVO_MAX_US);
	TVC_X_CH2.attach(TVC_X_CH2_PIN, SERVO_MIN_US, SERVO_MAX_US);
	TVC_Y_CH2.attach(TVC_Y_CH2_PIN, SERVO_MIN_US, SERVO_MAX_US);

	TVC_X_CH1.write(90+TVC_X_CH1_OFFSET); //Write all servos to center
	TVC_Y_CH1.write(90+TVC_Y_CH1_OFFSET);
	TVC_X_CH2.write(90+TVC_X_CH2_OFFSET);
	TVC_Y_CH2.write(90+TVC_Y_CH2_OFFSET);

	//Init serial
	if (debug) {
		Serial.begin(115200);
		debugPrintln("[INIT] hello!");
	}

	//Setup rocket for initial conditions before initialization
	configureInitialConditions(); 
	debugPrintln("[INIT] initconfig ok");

	boolean error = false;

	//Setup radio
	if (!radio.init()) {
		Serial.println("[INIT] Radio failed to initialize");
		error = true;
	} else {
		debugPrintln("[INIT] RADIO OK");
	}
	radio.setTxPower(23, false);
  	radio.setFrequency(868);

  	//Setup ms5611
  	if (!ms5611.begin()) {
  		Serial.println("[INIT] Baro failed to initialize");
  		error = true;
  	} else {
  		debugPrintln("[INIT] BARO OK");
  	}

  	//Setup flash
  	if (!flash.begin()) {
  		Serial.println("[INIT] Error initializing flash memory");
  		error = true;
  	} else {
  		debugPrint("[INIT] FLASH OK, SIZE=");
  		debugPrintln(flash.getCapacity());
  	}
  	flash.eraseChip();
  	debugPrintln("FLASH ERASE OK");

	//Setup SD card
	if (!SD.begin(SD_CS)) {
		debugPrintln("[INIT] Error initializing SD card");
		dataLoggingState = DL_DISABLED;
		error = true;
	} else {
		Serial.println("[INIT] SD OK");
	}

	char filename[] = "FLIGHT00.CSV";
	for (uint8_t i = 0; i < 100; i++) {
		filename[6] = i/10 + '0';
		filename[7] = i%10 + '0';
		if (!SD.exists(filename)) {
		 break;  // leave the loop!
		}
	}

	for (int i=0; i<sizeof(filename); i++) {
		dataLogFilename[i] = filename[i];
	}

	Serial.print("SDFilename: ");
	Serial.println(dataLogFilename);

	//Setup GPS
	if (GPS.begin(Wire, 0x42) == false) {
		Serial.println("[INIT] SAM-M8Q GPS module failed to initialize");
		error = true;
	} else {
		debugPrintln("[INIT] GPS INIT OK");
	}
	GPS.setI2COutput(COM_TYPE_UBX); //Set the I2C port to output UBX only (turn off NMEA noise)
	GPS.setNavigationFrequency(5); //Produce five solutions per second
	GPS.setAutoPVT(true); //Tell the GPS to "send" each solution
	GPS.saveConfiguration(); //Save the current settings to flash and BBR

	if (GPS.setDynamicModel(DYN_MODEL_AIRBORNE2g) == false) { // Set the dynamic model to airborne
		Serial.println("[INIT] GPS dynamic model set fail");
		error = true;
	}
	

	//Setup BMI088
	if (accel.begin() < 0) {
		Serial.println("[INIT] BMI088 accel failed to initialize");
		error = true;
	} else {
		debugPrintln("[INIT] ACCEL INIT OK");
	}
	if (gyro.begin() < 0) {
		Serial.println("[INIT] BMI088 gyro failed to initialize");
		error = true;
	} else {
		debugPrintln("[INIT] GYRO INIT OK");
	}

	//Setup ODR and range
	gyro.setOdr(Bmi088Gyro::ODR_2000HZ_BW_532HZ);
	gyro.setRange(Bmi088Gyro::RANGE_2000DPS);
	gyro.pinModeInt3(Bmi088Gyro::PUSH_PULL,Bmi088Gyro::ACTIVE_HIGH);
	gyro.mapDrdyInt3(true);
	attachInterrupt(ACCEL_INT, accel_drdy, RISING);

	accel.setOdr(Bmi088Accel::ODR_1600HZ_BW_280HZ);
	accel.setRange(Bmi088Accel::RANGE_24G);
	accel.pinModeInt1(Bmi088Accel::PUSH_PULL,Bmi088Accel::ACTIVE_HIGH);
	accel.mapDrdyInt1(true);
	attachInterrupt(GYRO_INT, gyro_drdy, RISING);

	//Setup ADS1015 #1
	if (!ADS1.begin()) {
		error = true;
		Serial.println("[INIT] ADS1 failed to initialize");
	} else {
		debugPrintln("[INIT] ADS1 OK");
	}
  	ADS1.setGain(1);
  	

  	//Setup ADS1015 #2
	if (!ADS2.begin()) {
		error = true;
		Serial.println("[INIT] ADS2 failed to initialize");
	} else {
		debugPrintln("[INIT] ADS2 OK");
	}
  	ADS2.setGain(1);

  	if (error) {
  		analogWrite(IND_G_PIN, 0);
  		analogWrite(IND_R_PIN, 127);
  		analogWrite(IND_B_PIN, 0);
  		while(1);
  	} else {
  		analogWrite(IND_G_PIN, 127);
  		analogWrite(IND_R_PIN, 0);
  		analogWrite(IND_B_PIN, 0);
  		delay(100);
  		analogWrite(IND_G_PIN, 0);
  		analogWrite(IND_R_PIN, 0);
  		analogWrite(IND_B_PIN, 0);
	}
	
}


EulerAngles gyroMeasure;
EulerAngles gyroOut;

Orientation ori;
float locX,locY,locZ;

float gbiasX, gbiasY, gbiasZ;
unsigned long biasStart;
int biasCount = 0;

unsigned long lastOriMicros;
unsigned long lastTVCMicros;
unsigned long lastAltMicros;

double currentAlt = 0;

const byte altBufferLen = 50;
double altBuffer[altBufferLen];
byte altBufferPos = 0;

double lastAlt = 0;
double altSlope = 0;
double launchAlt = 0;

unsigned long flightStartTime;

unsigned long lastDataloggingTime;
uint32_t currentFlashAddr = 0;

float fAbs(float n) {
	if (n < 0) {
		return -n;
	} else {
		return n;
	}
}

unsigned long lastNotLandedTime;

bool setState = false;

void loop() {
	/*
	MASTER FLIGHT LOOP
	*/
	unsigned long timeSinceFlightStart = millis() - flightStartTime;

	if (flightMode == CONN_WAIT) {
		if (telemetryConnectionState == TEL_CONNECTED) {
			Serial.println("TEL_CONN in wait");
			transitionMode(IDLE);
		}
	} else if (flightMode == IDLE) {
		if (telemetryConnectionState == TEL_DISCONNECTED) {
			Serial.println("TEL_DISCONN in idle");
			transitionMode(CONN_WAIT);
		}
	} else if (flightMode == LAUNCH) {
		//State transitions!

		/*
		Different ways the chutes can deploy:
		1) abort condition: >30deg over on roll or pitch axes after flight time abort
		2) derivative condition: slope of altitude is within a certain margin after flight begins
		3) force condition: if not already deployed, chutes will be forced to deploy after a certain number of seconds
		*/
		bool chutesAbort = timeSinceFlightStart > flight_minTimeBeforeAbort && (fAbs(locZ*57.2958) >= flight_abortDegrees || fAbs(locY*57.2958) >= flight_abortDegrees);
		bool chutesApogee = timeSinceFlightStart > flight_minTimeBeforeApogee && fAbs(altSlope) < flight_altSlopeApogeeCutoff && altSlope != 0;
		bool chutesForce = timeSinceFlightStart > flight_timeBeforeForceChutesDeploy;

		// Serial.print("conditions: abo=");
		// Serial.print(chutesAbort?"T":"F");
		// Serial.print(" apo=");
		// Serial.print(chutesApogee?"T":"F");
		// Serial.print(" for=");
		// Serial.println(chutesForce?"T":"F");
		if (chutesAbort || chutesApogee || chutesForce) {
			transitionMode(DESCEND);
		}
	} else if (flightMode == DESCEND) {
		if (fAbs(altSlope) < flight_altSlopeLandedCutoff) {
		} else {
			lastNotLandedTime = millis();
		}
		Serial.println(millis() - lastNotLandedTime);
		if (timeSinceFlightStart > flight_timeBeforeForceSDCopy || millis() - lastNotLandedTime > flight_minLandedTime) {
			transitionMode(COPYINGSD);
		}
	} else if (flightMode == COPYINGSD) {
		uint32_t addr = 0;
		TELEMETRY tlmOut;

		File dataFile = SD.open(dataLogFilename, FILE_WRITE);

		// if (dataFile) {
		// 	dataFile.println("timeSinceStartup,missionElapsedTime,guidanceFrequency,flightMode,pyroState,chuteState,dataLoggingState,telemSendState,telemConnState,battV,servoV,rollMotorV,boardTemp,gyroX,gyroY,gyroZ,alt,oriX,oriY,oriZ,tvcX,tvcY,pyro1Cont,pyro2Cont,pyro3Cont,pyro4Cont,pyro5Cont,pyro1Fire,pyro2Fire,pyro3Fire,pyro4Fire,pyro5Fire");
		// 	while (addr < flash.getCapacity()) {
		// 		flash.readAnything(addr, tlmOut);
		// 		if (isnan(tlmOut.battV)) {
		// 			break; //we got end
		// 		} else {
		// 			dataFile.print(tlmOut.timeSinceStartup);
		// 			dataFile.print(",");
		// 			dataFile.print(tlmOut.missionElapsedTime);
		// 			dataFile.print(",");
		// 			dataFile.print(tlmOut.guidanceFrequency);
		// 			dataFile.print(",");
		// 			dataFile.print(tlmOut.fMode);
		// 			dataFile.print(",");
		// 			dataFile.print(tlmOut.pState);
		// 			dataFile.print(",");
		// 			dataFile.print(tlmOut.cState);
		// 			dataFile.print(",");
		// 			dataFile.print(tlmOut.dState);
		// 			dataFile.print(",");
		// 			dataFile.print(tlmOut.tSState);
		// 			dataFile.print(",");
		// 			dataFile.print(tlmOut.tCState);
		// 			dataFile.print(",");
		// 			dataFile.print(tlmOut.battV);
		// 			dataFile.print(",");
		// 			dataFile.print(tlmOut.servoV);
		// 			dataFile.print(",");
		// 			dataFile.print(tlmOut.rollMotorV);
		// 			dataFile.print(",");
		// 			dataFile.print(tlmOut.boardTemp);
		// 			dataFile.print(",");
		// 			dataFile.print(tlmOut.gyroX);
		// 			dataFile.print(",");
		// 			dataFile.print(tlmOut.gyroY);
		// 			dataFile.print(",");
		// 			dataFile.print(tlmOut.gyroZ);
		// 			dataFile.print(",");
		// 			dataFile.print(tlmOut.alt);
		// 			dataFile.print(",");
		// 			dataFile.print(tlmOut.oriX);
		// 			dataFile.print(",");
		// 			dataFile.print(tlmOut.oriY);
		// 			dataFile.print(",");
		// 			dataFile.print(tlmOut.oriZ);
		// 			dataFile.print(",");
		// 			dataFile.print(tlmOut.tvcX);
		// 			dataFile.print(",");
		// 			dataFile.print(tlmOut.tvcY);
		// 			dataFile.print(",");
		// 			dataFile.print(tlmOut.pyro1Cont);
		// 			dataFile.print(",");
		// 			dataFile.print(tlmOut.pyro2Cont);
		// 			dataFile.print(",");
		// 			dataFile.print(tlmOut.pyro3Cont);
		// 			dataFile.print(",");
		// 			dataFile.print(tlmOut.pyro4Cont);
		// 			dataFile.print(",");
		// 			dataFile.print(tlmOut.pyro5Cont);
		// 			dataFile.print(",");
		// 			dataFile.print(tlmOut.pyro1Fire);
		// 			dataFile.print(",");
		// 			dataFile.print(tlmOut.pyro2Fire);
		// 			dataFile.print(",");
		// 			dataFile.print(tlmOut.pyro3Fire);
		// 			dataFile.print(",");
		// 			dataFile.print(tlmOut.pyro4Fire);
		// 			dataFile.print(",");
		// 			dataFile.print(tlmOut.pyro5Fire);
		// 			dataFile.println();
		// 		}
		// 		addr+=sizeof(TELEMETRY);
		// 	}
		// 	dataFile.close();
		// } else {
		// 	Serial.println("ERROR opening SD file");
		// }
		transitionMode(LANDED);
	}

	/*
	ESSENTIAL ORIENTATION CALCULATIONS
	*/
	double dtOri = (double)(micros()-lastOriMicros) / 1000000.0;
	if (dtOri > ORI_CALC_DELTA) {
		if (oriMode == COMPLEMENTARY && gyro_ready && accel_ready) {
			gyro_ready = false;
			accel_ready = false;

			gyro.readSensor();

			gyroMeasure.roll = (gyro.getGyroX_rads() + gbiasX);
			gyroMeasure.pitch = -(gyro.getGyroZ_rads() + gbiasY);
			gyroMeasure.yaw = -(gyro.getGyroY_rads() + gbiasZ);


			ori.update(gyroMeasure, dtOri);

			accel.readSensor();
			Quaternion accVec(accel.getAccelX_mss(), -(accel.getAccelZ_mss()), -(accel.getAccelY_mss()));

			ori.applyComplementary(accVec,0.02);
		} else if (oriMode == GYRONLY && gyro_ready) {
			gyro_ready = false;

			gyro.readSensor();
			gyroMeasure.roll = (gyro.getGyroX_rads() + gbiasX);
			gyroMeasure.pitch = -(gyro.getGyroZ_rads() + gbiasY);
			gyroMeasure.yaw = -(gyro.getGyroY_rads() + gbiasZ);

			ori.update(gyroMeasure, dtOri);
		} else if (oriMode == CALCBIASES && gyro_ready) {
			gyro_ready = false;

			gyro.readSensor();
			gbiasX += (double)gyro.getGyroX_rads();
			gbiasY += (double)gyro.getGyroY_rads();
			gbiasZ += (double)gyro.getGyroZ_rads();
			biasCount++;

			if (micros() - biasStart > 3000000) { //1.5sec
				Serial.println("BIASCOUNT");
				Serial.println(biasCount);
				gbiasX /= biasCount; //Find bias in 1 reading
				gbiasY /= biasCount;
				gbiasZ /= biasCount;

				Serial.print("gbiasX=");
				Serial.println(gbiasX, 5);
				Serial.print("gbiasY=");
				Serial.println(gbiasY, 5);
				Serial.print("gbiasZ=");
				Serial.println(gbiasZ, 5);
				oriMode = GYRONLY;
			}
		} else {
			biasStart = micros();
			oriMode = CALCBIASES;
		}

		if (gyro_ready) {
			gyro.readSensor();
			telem.gyroX = (gyro.getGyroX_rads() + gbiasX);
			telem.gyroY = -(gyro.getGyroY_rads() + gbiasY);
			telem.gyroZ = -(gyro.getGyroZ_rads() + gbiasZ);

			telem.gyroX = gyroMeasure.roll;
			telem.gyroY = gyroMeasure.yaw;
			telem.gyroZ = gyroMeasure.pitch;
		}
		if (accel_ready) {
			accel.readSensor();
			telem.accX = accel.getAccelX_mss();
			telem.accY = accel.getAccelY_mss();
			telem.accZ = accel.getAccelZ_mss();
		}

		gyroOut = ori.toEuler();

		locX = gyroOut.roll*GYRO_MULT;
		locY = gyroOut.pitch*GYRO_MULT; //pid x
		locZ = gyroOut.yaw*GYRO_MULT; //pid y

		zAxis.update(locZ*57.2958, dtOri);
	  	yAxis.update(locY*57.2958, dtOri);
	  	lastOriMicros = micros();
	}

	/*
	PID UPDATES
	*/
	double dtTVC = (double)(micros()-lastTVCMicros) / 1000000.0;
	if (dtTVC > SERVO_WRITE_DELTA && tvcEnabled == TVC_ENABLED) {
		float zAng = zAxis.getLast();
		float yAng = yAxis.getLast();

		//Roll correction required
		double cs = cos(-locX);
		double sn = sin(-locX);
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

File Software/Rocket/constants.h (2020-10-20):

#ifndef constants_h
#define constants_h

#include "Arduino.h"

/*
TVC OFFSETS
*/

//Channel 1
#define TVC_X_CH1_OFFSET 0.0
#define TVC_Y_CH1_OFFSET 0.0
//Channel 2
#define TVC_X_CH2_OFFSET 0.0
#define TVC_Y_CH2_OFFSET 0.0

/*
PID VALUES
*/

const float PID_Z_P = 2;
const float PID_Z_I = 2;
const float PID_Z_D = 0.07;

const float PID_Y_P = 2;
const float PID_Y_I = 2;
const float PID_Y_D = 0.07;

//WORKING
// const float PID_Z_P = 1.5;
// const float PID_Z_I = 0.00;
// const float PID_Z_D = 0.2;

// const float PID_Y_P = 1.5;
// const float PID_Y_I = 0.00;
// const float PID_Y_D = 0.2;

#define GYRO_MULT 2.917

#define ORI_CALC_FREQ 2000
#define SERVO_WRITE_FREQ 250

const double SERVO_WRITE_DELTA = 1.0/(double)SERVO_WRITE_FREQ;
const double ORI_CALC_DELTA = 1.0/(double)ORI_CALC_FREQ;
/*
SERVO CONSTANTS
*/
#define SERVO_MULT 4
#define SERVO_RANGE_X 10
#define SERVO_RANGE_Y 10

#define SERVO_MIN_US 900 //us`
#define SERVO_MAX_US 2100 //us

/*
RADIO CONSTANTS
*/
#define RADIO_DELAY 75 //ms

/*
BAROMETER CONSTANTS
*/
#define BARO_CALC_FREQ 100

const double BARO_CALC_DELTA = 1.0/(double)BARO_CALC_FREQ;

/*
ADC RESISTOR DIVIDER CALCUALTIONS
*/
const short ADC_VBUS_DIVD_RES1 = 1000; //VBUS = main input voltage, 12.6V max
const short ADC_VBUS_DIVD_RES2 = 330;
const double ADC_RES_DIV_FACTOR_VBUS = (double)ADC_VBUS_DIVD_RES2/((double)ADC_VBUS_DIVD_RES1+(double)ADC_VBUS_DIVD_RES2);

const short ADC_VSERVO_DIVD_RES1 = 1000; //VSERVO = servo voltage rail
const short ADC_VSERVO_DIVD_RES2 = 620;
const double ADC_RES_DIV_FACTOR_VSERVO = (double)ADC_VSERVO_DIVD_RES2/((double)ADC_VSERVO_DIVD_RES1+(double)ADC_VSERVO_DIVD_RES2);

const short ADC_VMOTOR_DIVD_RES1 = 560; //VMOTOR = roll motor voltage rail
const short ADC_VMOTOR_DIVD_RES2 = 680;
const double ADC_RES_DIV_FACTOR_VMOTOR = (double)ADC_VMOTOR_DIVD_RES2/((double)ADC_VMOTOR_DIVD_RES1+(double)ADC_VMOTOR_DIVD_RES2);

const short ADC_PYRO_DIVD_RES1 = 1000; //PYRO = Pyro voltage, same as VBUS in this version of the flight controller
const short ADC_PYRO_DIVD_RES2 = 330;
const double ADC_RES_DIV_FACTOR_PYRO = (double)ADC_PYRO_DIVD_RES2/((double)ADC_PYRO_DIVD_RES1+(double)ADC_PYRO_DIVD_RES2);

const double ADC_MAX_V = 4.096;
const double ADC_DIV_FACTOR_V = ADC_MAX_V/2047; //11 bit mantissa

const float ADC_PYRO_THRESH_CONT = 11.5; //voltage drop in v for cont

/*
MISC CONSTANT SETTINGS
*/

const bool buzzerEnabled = false;
const bool indicatorEnabled = true;

/*
FLIGHT TRANSITION CONSTANTS
*/

//Parachute deployment stuff
#define flight_minTimeBeforeApogee 5500
#define flight_altSlopeApogeeCutoff 2

#define flight_timeBeforeForceChutesDeploy 7000

#define flight_minTimeBeforeAbort 4000
#define flight_abortDegrees 30

#define flight_timeBeforeForceSDCopy 45000
#define flight_altSlopeLandedCutoff 1.5
#define flight_minLandedTime 1250


/*
DATALOGGING CONSTANTS
*/


#endif

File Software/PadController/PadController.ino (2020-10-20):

#include <SPI.h>
#include <SPI.h>
#include <RH_RF95.h>
#include "states.h"
#include "pindefs.h"
#include <Arduino.h>
#include <U8g2lib.h>

#ifdef U8X8_HAVE_HW_SPI
#include <SPI.h>
#endif
#ifdef U8X8_HAVE_HW_I2C
#include <Wire.h>
#endif

/*
DISPLAY
*/

U8G2_ST7565_NHD_C12832_F_4W_HW_SPI u8g2(U8G2_R0, /* cs=*/ 9, /* dc=*/ 5, /* reset=*/ 10);
long lastDisplayUpdateTime = 0;
const int displayUpdateDelay = 500;

/*
RADIO
*/
RH_RF95 radio(RADIO_CS, RADIO_IRQ);

struct RadioPacket {
	uint8_t id;
	uint8_t subID;
	float data1;
	float data2;
	float data3;
};

const byte radioQueueLength = 25;
RadioPacket radioPacketQueue[radioQueueLength];
unsigned long lastRadioSendTime = 0;
byte radioStackPos = 0;
#define RADIO_DELAY 100

/*
Radio Command List
0: Ping/pong check (heartbeat)
1: GetRocketState
2: SetRocketState
3: RocketTelem
sub IDs:
	0 - time since startup, MET, loop freq
	1 - flightmode, pyrostates, chutestates
	2 - dataloggingstates, telemsendstates, telemconnstates
	3 - battv, servov, rollmotorv
	4 - boardtemp, gpsfix, gpssats
	5 - gyro x, y, z
	6 - acc x, y, z
	7 - mag x, y, z
	8 - gnss lat, gnss lon, alt
	9 - ori x, y, z
	10 - pos x, y, z
	11 - vel x, y, z
	12 - pyro1 cont, pyro2 cont, pyro3 cont
	13 - pyro4 cont, pyro5 cont, blank
	14 - pyro1 fire, pyro2 fire, pyro3 fire
	15 - pyro4 fire, pyro5 fire, blank	
	16 - tvc x, tvc y, blank
4: RequestRocketTelem
5: Enable/Disable Pyros
6: FirePyro
*/

typedef enum {
	HEARTBEAT = 0,
	GETSTATE = 1,
	SETSTATE = 2,
	GETTELEM = 3,
	REQTELEM = 4,
	PYROARMING = 5,
	FIREPYRO = 6
} RadioCommands;

unsigned long lastRadioRecieveTime = 0;


/*
TELEMETRY STRUCT
*/

struct TELEMETRY {
	//Raw vehicle information
	unsigned long timeSinceStartup;
	unsigned long missionElapsedTime;
	double guidanceFrequency;

	//State stuff
	FlightMode fMode;
	PyroStates pState;
	ChuteStates cState;
	DataLoggingStates dState;
	TelemSendStates tSState;
	TelemConnStates tCState;

	//Basic sensor data
	float battV;
	float servoV;
	float rollMotorV;
	float boardTemp;

	//Raw sensor data
	double gyroX;
	double gyroY;
	double gyroZ;
	double accX;
	double accY;
	double accZ;
	double magX;
	double magY;
	double magZ;
	double GNSSLat;
	double GNSSLon;
	double alt;

	//Calculated state vector data
	double oriX;
	double oriY;
	double oriZ;
	double posX;
	double posY;
	double posZ;
	double velX;
	double velY;
	double velZ;

	//TVC Data
	double tvcX;
	double tvcY;
	
	//GNSS locking data
	byte gpsFix;
	int gpsSats;

	//Pyro channel data
	bool pyro1Cont;
	bool pyro2Cont;
	bool pyro3Cont;
	bool pyro4Cont;
	bool pyro5Cont;
	bool pyro1Fire;
	bool pyro2Fire;
	bool pyro3Fire;
	bool pyro4Fire;
	bool pyro5Fire;
};
struct TELEMETRY telem;


int rocketHBPacketCount = 0;
unsigned long lastPacketPrint = 0;
const int packetPrintDelay = 1000;

unsigned long lastHeartbeat = 0;
const int heartbeatDelay = 100;

String serialBuffer = "";

void setup() {

	Serial.begin(115200);
	//Setup pin states
	pinMode(IND_R_PIN, OUTPUT);
	pinMode(IND_G_PIN, OUTPUT);
	pinMode(IND_B_PIN, OUTPUT);
	pinMode(BUZZER_PIN, OUTPUT);

	analogWrite(IND_B_PIN, 55);

	int t = 1400;
	for (int i=0; i<3; i++) {
		tone(BUZZER_PIN, t);
		t+=200;
		delay(100);
	}
	noTone(BUZZER_PIN);

	bool error = false;
	if (!radio.init()) {
		error = true;
	}
	radio.setTxPower(23, false);
  	radio.setFrequency(868);

  	if (!u8g2.begin()) {
  		error = true;
  	}
  	u8g2.setFontMode(1);
  	u8g2.setFlipMode(1);

  	if (error) {
  		analogWrite(IND_G_PIN, 0);
  		analogWrite(IND_R_PIN, 55);
  		analogWrite(IND_B_PIN, 0);
  		while(1);
  	} else {
  		analogWrite(IND_G_PIN, 55);
  		analogWrite(IND_R_PIN, 0);
  		analogWrite(IND_B_PIN, 0);
  	}
  	delay(1000);
}

float packetRate;
int rssi;
bool confirmLaunch = false;

bool sendLaunch = false;
unsigned long launchStartTime = 0;

void loop() {
	unsigned long currentMillis = millis();

	if (currentMillis - lastPacketPrint >= packetPrintDelay) {
		packetRate = rocketHBPacketCount/(packetPrintDelay/1000);
		rssi = (int)radio.lastRssi();
		int rValue = map(packetRate, 0, 5, 64, 0);
		int gValue = map(packetRate, 0, 5, 0, 64);
		analogWrite(IND_G_PIN, gValue);
		analogWrite(IND_R_PIN, rValue);

		Serial.print("Rate=");
		Serial.print(packetRate);
		Serial.print("Hz\tRSSI=");
		Serial.println(rssi, DEC);

		rocketHBPacketCount = 0;
		lastPacketPrint = currentMillis;
	}

	if (currentMillis - lastDisplayUpdateTime >= displayUpdateDelay) {
		u8g2.clearBuffer();

		//Write TLM rate
		u8g2.setFont(u8g2_font_helvR08_tf);
		u8g2.setCursor(0,8);
    	u8g2.print("TLM Hz");
    	u8g2.setCursor(0,32);
    	u8g2.setFont(u8g2_font_logisoso16_tf);
    	u8g2.print(packetRate);

    	//Write rssi
    	u8g2.setFont(u8g2_font_helvR08_tf);
		u8g2.setCursor(40,8);
    	u8g2.print("RSSI");
    	u8g2.setCursor(40,32);
    	u8g2.setFont(u8g2_font_logisoso16_tf);
    	u8g2.print(rssi);

    	//Write pyro states
    	u8g2.setFont(u8g2_font_helvR08_tf);
		u8g2.setCursor(70,32);
    	u8g2.print("Cont=");
    	u8g2.print((telem.pyro1Cont)?"T":"F");
    	u8g2.print((telem.pyro2Cont)?"T":"F");
    	u8g2.print((telem.pyro3Cont)?"T":"F");
    	u8g2.print((telem.pyro4Cont)?"T":"F");
    	u8g2.print((telem.pyro5Cont)?"T":"F");

    	//Write voltage rails
    	u8g2.setFont(u8g2_font_helvR08_tf);
		u8g2.setCursor(70,8);
    	u8g2.print("V=");
    	u8g2.print(telem.battV);
    	u8g2.print(",");
    	u8g2.print(telem.servoV);

    	//Write altitude
    	u8g2.setFont(u8g2_font_helvR08_tf);
		u8g2.setCursor(70,20);
    	u8g2.print("Alt=");
    	u8g2.print(telem.alt);

    	u8g2.sendBuffer();

    	lastDisplayUpdateTime = currentMillis;
	}

	if (currentMillis - lastHeartbeat > heartbeatDelay) {
		addRadioPacketToQueue(HEARTBEAT, 0, 0, 0, 0);
		lastHeartbeat = currentMillis;
	}

	if (Serial.available() > 0) {
		char inChar = Serial.read();

		if (inChar == ';') {
			serialBuffer.toLowerCase().trim();
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

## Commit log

2020-09-26 parachute dep
    [BPS_Piston_Ejection_-_Coupler_Bulkhead.stl, BPS_Piston_Ejection_-_Piston_Bulkhead.stl]
2020-09-28 updated file structure and added progress pictures
    [BPS_Piston_Ejection_-_Piston_Bulkhead.SLDPRT, nosecone.SLDPRT, nosecone.STL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]
2020-10-02 cad part 1
    [BPS_Piston_Ejection_-_Coupler_Bulkhead.stl, BPS_Piston_Ejection_-_Piston_Bulkhead.SLDPRT, BPS_Piston_Ejection_-_Piston_Bulkhead.stl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]
2020-10-08 updated ee stuff for the lads on bps discord
    [1327K930_MINIATURE 12L14 DRIVE STEEL SHAFT.SLDPRT, 57155K207_STAINLESS STEEL BALL BEARING.SLDPRT, 9414T300_SET SCREW SHAFT COLLAR.SLDPRT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]
2020-10-09 designed test fixture stuff and roll wheel updates
    [all gimbal stuff.3mf, all roll stuff.3mf, clampingSpacer.SLDPRT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]
2020-10-11 fixed axes inversion and issues
    [Rocket.ino, constants.h]
2020-10-15 upload because power might do a die
    [box.SLDPRT, box.STL, gear1-90.STL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]
2020-10-16 lotsa fixes but oop i gotta fly in 2 days
    [PadController.ino, RadioStructRecv.ino, Rocket.ino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]
2020-10-20 it went
    [FLIGHT03.CSV, FLIGHT04.CSV]
2020-10-21 final solidworks modelling
    [gear2.SLDPRT, guidance computer assem.SLDASM, rocket v1.SLDASM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]
2020-10-26 updated ee stuff
    [ZenithController.brd, ZenithController.csv, ZenithController.sch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]
2020-11-02 solidworks sims and references for v2
    [gimbalAssem.SLDASM, guidance computer assem.SLDASM, nosecone.SLDPRT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]
2021-01-06 to go with ground station software
    [rocket v1 for stl display.SLDASM, rocket v1 for stl display.STL]
2021-03-13 i2c tester stuff works

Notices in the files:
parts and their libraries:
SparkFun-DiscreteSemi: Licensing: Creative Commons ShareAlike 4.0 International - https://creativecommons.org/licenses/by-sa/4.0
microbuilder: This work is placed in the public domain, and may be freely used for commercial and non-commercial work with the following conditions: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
